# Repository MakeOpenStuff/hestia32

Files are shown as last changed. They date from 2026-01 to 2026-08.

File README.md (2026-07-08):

# Hestia32




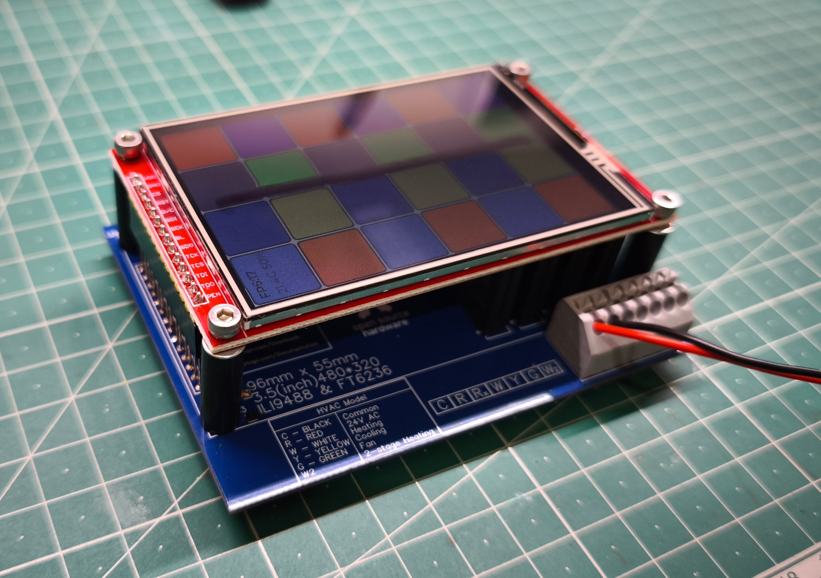
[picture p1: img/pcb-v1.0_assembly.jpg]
Hestia32 PCB Assembly


ESP32 firmware with WiFi provisioning, OTA updates, ILI9488 display, resistive touch and factory reset support.

## Supported Hardware

- **ESP32-C5** - RISC-V based ESP32 variant
- **ILI9488 Display** - 3.5" 320x480 IPS display with XPT2046 resistive touch

## Features

### HVAC Control
- **Multi-stage thermostat logic** - Separate control for heating, cooling, and hot water domains
- **Stage 2 support** - Progressive power control with time-delay and deviation thresholds
- **Comfort and ECO modes** - Adjustable temperature deadbands (±0.5°C comfort, ±1.0°C eco)
- **Hysteresis protection** - 5-minute delay prevents rapid mode switching
- **Fan pre/post-run** - Ensures airflow before heating elements activate and distributes residual heat/cool
- **Open-window detection** - Automatically suspends heating on rapid temperature drops to save energy

### Per-Domain Boost Feature
- Temporarily override thermostat logic for heating, cooling, or hot water
- Maximum output for user-defined countdown period
- Independent boost timer and duration memory per domain
- Automatic return to normal operation when boost expires

### Hardware & UI
- **3.5" ILI9488 Display** (320x480 IPS) with resistive touch (XPT2046)
- **LVGL-based graphical interface** with smooth animations
- **Automatic touch calibration** on first boot
- **Resistive touch coordinate mapping** for accurate input
- **Configurable sensor input** (SHT45 temperature/humidity)
- **5× SPST-NO dry-contact relay outputs** — shared common terminal plus five independent returns; activating a relay shorts its return to common (wire common to R in HVAC systems or N in EU mains wiring)

### Communication & Provisioning
- **WiFi provisioning** via web interface in AP (access point) mode
- **OTA (Over-The-Air) firmware updates** with stable/develop channel selection
- **Multiple protocol support:**
  - **MQTT** (fully implemented, production-ready)
  - **Zigbee** (protocol stub, framework ready)
  - **Matter** (protocol stub, framework ready)
- **Configurable node name and OTA server URL**
- **Factory reset** via BOOT button long-press (5 seconds)
- **NVS persistent storage** for WiFi credentials, calibration, and user settings

### Hardware Variants
- **ESP32-C5 RISC-V** - Primary target (full support)
- **Multiple board profiles:**
  - DevKit (standard GPIO pin assignment)
  - XIAO (compact form factor, alternative pins)
- **Regional variants:**
  - EU (European power levels and configurations)
  - HVAC (heating/cooling optimized)

## Prerequisites

### Display Hardware (ESP32-C5)
- **ILI9488 3.5" IPS Display** (320x480 resolution)
- **XPT2046 Touch Controller** (resistive)
- See [WIRING.md](WIRING.md) for complete pin connections
- **Important:** Display MISO must be disconnected - GPIO 2 is dedicated to touch controller

### For ESP32 (PlatformIO)
- [PlatformIO](https://platformio.org/) installed
- USB drivers for your ESP32 board

### For ESP32-C5 (ESP-IDF v5.5)
- ESP-IDF v5.5.2 or later (official C5 support)
- Python 3.8+
- CMake 3.16+
- Ninja build system

### For Testing (Native Host)
- GCC or Clang compiler with C11 support
- Make (optional, for convenient build commands)

## Building and Flashing

### Clone Repository

**Important:** This project uses git submodules (LVGL). Always clone with `--recursive`:

```bash
# Clone with submodules
git clone --recursive https://github.com/MakeOpenStuff/hestia32.git
cd hestia32

# Or if you already cloned without --recursive:
git submodule update --init --recursive
```

### ESP32 (NodeMCU-32S) - PlatformIO

```bash
# Build
pio run -e nodemcu-32s

# Upload
pio run -e nodemcu-32s -t upload

# Monitor
pio device monitor
```

### ESP32-C5 - Native ESP-IDF

#### First Time Setup

```bash
# Clone ESP-IDF v5.5.2 (one time only)
cd ~/esp
git clone --recursive --branch v5.5.2 https://github.com/espressif/esp-idf.git esp-idf-v5.5

# Install ESP-IDF tools for ESP32-C5 (one time only)
cd ~/esp/esp-idf-v5.5
./install.sh esp32c5
```

#### Protocol Selection

Hestia32 supports multiple communication protocols. Choose one when building:

**MQTT over WiFi (Default - Fully Implemented)**
```bash
idf.py -D SDKCONFIG_DEFAULTS=sdkconfig.mqtt build
```

**Zigbee (Stub Only - Not Yet Implemented)**
```bash
idf.py -D SDKCONFIG_DEFAULTS=sdkconfig.zigbee build
```

**Matter (Stub Only - Not Yet Implemented)**
```bash
idf.py -D SDKCONFIG_DEFAULTS=sdkconfig.matter build
```

You can also select the protocol interactively:
```bash
idf.py menuconfig
# Navigate to: Hestia32 Configuration → Communication Protocol
```

To check which protocol is currently selected:
```bash
grep "CONFIG_HESTIA32_PROTOCOL" sdkconfig
```

#### Build Commands

```bash
# Set up environment (required in each new terminal session)
source ~/esp/esp-idf-v5.5/export.sh

# Or use the provided script
./setup-c5.sh

# Configure target (first time only)
idf.py set-target esp32c5

# Build firmware
idf.py build

# Erase flash (removes all data including WiFi credentials)
idf.py -p /dev/ttyUSB0 erase-flash

# Flash firmware
idf.py -p /dev/ttyUSB0 flash

# Monitor serial output
idf.py -p /dev/ttyUSB0 monitor

# Flash and monitor in one command
idf.py -p /dev/ttyUSB0 flash monitor
```

**Note:** Replace `/dev/ttyUSB0` with your actual serial port (e.g., `/dev/ttyACM0`, `COM3` on Windows, `/dev/cu.usbserial-*` on macOS). Also prefer the (upper) port labelled UART (avoid USB or Native).

## Testing

### Thermostat Logic Tests

The firmware includes a comprehensive test suite for the thermostat control logic that runs on your development machine (not on the ESP32).

#### Running Tests

```bash
# Quick test (using Makefile)
make test

# Or manually build and run
gcc -Wall -Wextra -std=c11 -I. src/thermostat.c tests/test_thermostat.c -o test_thermostat -lm && ./test_thermostat
```

#### Test Coverage

The test suite validates:

1. **Configuration validation** - Domain limits, setpoint sanity checks
2. **Hysteresis protection** - Prevents rapid state changes (300s delay)
3. **Comfort deadband** - Temperature activation thresholds (±0.5°C)
4. **ECO deadband** - Wider temperature band for energy savings (±1.0°C)
5. **Stage 2 heating** - Gradual power increase with delay + deviation logic
6. **Stage 2 cooling** - Gradual power increase with delay + deviation logic
7. **Mutual exclusion** - Heating and cooling never run simultaneously
8. **Sensor failure safety** - Automatic shutdown on sensor faults
9. **Temperature units** - Celsius and Fahrenheit conversion
10. **Fan control** - Pre-run (30s), post-run (60s), and manual override
11. **Humidity control** - Humidification and dehumidification with deadband
12. **Hot water demand** - On-demand hot water heating
13. **Fan timing** - Comprehensive pre-run and post-run validation
14. **Hysteresis + HVAC** - State change delays with fan coordination
15. **Comfort deadband + HVAC** - Temperature thresholds with fan safety
16. **ECO deadband + HVAC** - Energy-saving mode with fan coordination
17. **Stage 2 heating + HVAC** - Multi-stage heating with fan timing
18. **Stage 2 cooling + HVAC** - Multi-stage cooling with fan timing
19. **Mutual exclusion + HVAC** - No simultaneous operation through all fan phases
20. **Sensor failure + HVAC** - Immediate shutdown including fan (safety critical)
21. **Open window detection** - Detects rapid temperature drops, suspends heating to save energy
22. **Open window false positive prevention** - Validates gradual changes don't trigger detection

**Scenario Testing:**
- **24-hour simulation** - Complete heating cycle with realistic temperature changes

**Key Features Validated:**
- Fan pre-run ensures airflow before thermal elements activate (prevents dry running)
- Fan post-run distributes residual heat/cool after thermal stops
- Minimum cycle time (180s) protects equipment from short cycling
- Hysteresis period (300s) prevents rapid mode switching
- Stage 2 activation requires both time delay (300s) AND temperature deviation (0.75°C)
- All outputs shut down immediately on sensor failure (safety)
- Manual fan override works independently of thermal state

#### Test Output

Tests produce color-coded output (green = pass, red = fail) with:
- Related configuration for each test
- Step-by-step execution traces
- Final summary table with pass/fail counts

```
=== TEST 1: Configuration Validation ===
Testing: thermostat_config_validate() with various invalid configs
...
✓ PASSED: Configuration Validation

=== SUMMARY ===
Total Tests: 12
Passed: 12
Failed: 0
Success Rate: 100.00%
```

#### Continuous Testing

Run tests before committing changes to ensure thermostat logic correctness:

## Usage

### Initial Setup (Provisioning)

1. Flash the firmware to your device
2. On first boot, the device creates a WiFi access point:
	 - **SSID:** `HESTIA32`
	 - **Password:** None (open network)
3. Connect to the `HESTIA32` WiFi network
4. Open a web browser and navigate to `http://192.168.4.1`
5. Enter your WiFi credentials and configuration:
	 - WiFi SSID
	 - WiFi Password
	 - Node Name (optional)
	 - OTA Server URL (optional)
6. Click Save - the device will restart and connect to your WiFi

### Factory Reset

To erase WiFi credentials, touch calibration, and return to provisioning mode:

1. Power off the device
2. Press and hold the **BOOT** button
3. Power on the device (or press RESET while holding BOOT)
4. Keep holding the BOOT button for **5 seconds**
5. Release when you see "Factory reset confirmed!" in the serial monitor
6. The device will erase all NVS data and reboot into provisioning mode

**BOOT Button GPIO:**
- ESP32 (original): GPIO 0
- ESP32-C5: GPIO 28

**Troubleshooting:** Check serial monitor for "BOOT button GPIO X level: 0" when button is pressed. If it shows "1", the GPIO may be incorrect for your board.

## Configuration

Edit `src/config.h` to customize:

```c
#define PROV_AP_SSID "HESTIA32"          // Provisioning AP name
#define PROV_AP_PASSWORD ""               // AP password (empty = open)
#define OTA_SERVER_URL "https://..."      // Default OTA server
#define OTA_CHECK_INTERVAL_MS 300000      // OTA check interval (5 min)
#define APP_VERSION "1.0.0"               // Firmware version
```

## Project Structure

```
hestia32/
├── src/
│   ├── main.c                      # Application entry point
│   ├── core/                       # Core thermostat & hardware functionality
│   │   ├── core_config.h           # Firmware version and core settings
│   │   ├── thermostat.c/h          # HVAC control logic (stages, hysteresis, deadbands)
│   │   ├── relay_manager.c/h       # Heating, cooling, hot water, fan output control
│   │   ├── sensor_sht45.c/h        # Temperature/humidity sensor interface
│   │   ├── protocol_manager.c/h    # Protocol abstraction and selection
│   │   ├── user_settings.c/h       # NVS persistent storage (WiFi, calibration, settings)
│   │   ├── display_manager.h       # Display abstraction layer
│   │   ├── display_ui.h            # LVGL UI components and screens
│   │   └── display_config.h        # Display initialization (ILI9488, XPT2046)
│   └── protocols/                  # Communication protocol implementations
│       ├── protocol_interface.h    # Common interface for all protocols
│       ├── mqtt/                   # MQTT over WiFi (production-ready)
│       │   ├── mqtt_protocol.c/h   # MQTT client and message handling
│       │   ├── wifi_manager.c/h    # WiFi connection management
│       │   ├── wifi_provisioning.c/h # Web-based provisioning (AP mode)
│       │   ├── ota_manager.c/h     # OTA update checking and flashing
│       │   ├── mqtt_config.h       # MQTT broker configuration
│       │   └── provisioning_html.h # Embedded provisioning web UI
│       ├── zigbee/                 # Zigbee (protocol stub)
│       │   └── protocol_zigbee.c/h
│       └── matter/                 # Matter (protocol stub)
│           └── protocol_matter.c/h
├── components/
│   ├── esp_lcd_ili9488/            # ILI9488 display driver
│   └── lvgl/                       # LVGL graphics library (submodule)
├── pcb/                            # Hardware designs and manufacturing files
│   └── README.md                   # PCB revision history and board notes
├── docs/                           # Technical documentation
│   ├── display/                    # Display configuration guides
│   ├── esp32-c5/                   # ESP32-C5 specific documentation
│   └── sensors/                    # Sensor integration docs
├── tests/
│   ├── test_thermostat.c           # Comprehensive thermostat logic test suite (24 tests)
│   └── Makefile                    # Test build automation
├── platformio.ini                  # PlatformIO configuration (ESP32 support)
├── CMakeLists.txt                  # ESP-IDF build config (ESP32-C5 primary)
├── sdkconfig.defaults              # ESP-IDF default settings
├── sdkconfig.mqtt/zigbee/matter    # Protocol-specific SDK configurations
├── Makefile                        # Build and test automation
├── setup-c5.sh                     # ESP32-C5 environment setup script
├── WIRING.md                       # Complete pin mapping for all board variants
├── Hestia32-FSD.md                 # Functional specification document
└── README.md                       # This file
```

## Troubleshooting

### ESP32-C5 Build Issues

**Error: `idf.py: command not found`**
```bash
source ~/esp/esp-idf-v5.5/export.sh
```

**Error: WiFi/PHY undefined references**
- Make sure you're using ESP-IDF v5.5.1 or later
- ESP32-C5 support is incomplete in earlier versions

**Error: unexpected command options**
- Use plain `idf.py` commands with no extra preview options

### Serial Port Not Found

```bash
# Linux - check available ports
ls /dev/tty*

# Add user to dialout group (Linux)
sudo usermod -a -G dialout $USER
# Log out and back in for changes to take effect

# macOS - check available ports
ls /dev/cu.*
```

### Device Stuck in Provisioning Mode

If the device won't connect to WiFi after provisioning:

1. Check serial monitor for error messages
2. Verify WiFi credentials are correct
3. Perform factory reset and re-provision
4. Check that your WiFi network is 2.4GHz (ESP32 doesn't support 5GHz)

### Test Failures

If thermostat tests fail:

1. Check that you have a C11-compatible compiler:
	 ```bash
	 gcc --version  # Should be 4.9 or later
	 ```

2. Ensure all source files are present:
	 ```bash
	 ls src/thermostat.c src/thermostat.h tests/test_thermostat.c
	 ```

3. Run with verbose output to see which test failed:
	 ```bash
	 ./build/test_thermostat
	 ```

4. If colors don't display correctly, your terminal may not support ANSI codes

## TODO

### Known Issues & Pending Tasks

- [ ] **WiFi Model**
	- [ ] Fix serial logging on DevKit - Serial output stops after bootloader on ESP32-C5 DevKit, investigate USB re-enumeration or UART configuration
	- [ ] Verify SHT45 operation on DevKit - Confirm sensor reads correctly with swapped I2C pins (SDA=GPIO5, SCL=GPIO4)
	- [ ] Update WIRING.md pinout diagram - Reconcile conflicting GPIO assignments in DevKit pinout diagram vs. connection tables
	- [ ] Update Project Structure section - Reflect current codebase organization with display, relay, and sensor modules
- [ ] **UI Design & Implementation**
	- [ ] Design and implement main thermostat control interface
	- [ ] Create settings/configuration screens
	- [ ] Implement touch interactions and navigation
	- [ ] Add visual feedback for heating/cooling states
- [ ] **Zigbee Model**
- [ ] **Matter Model**

## License

This project uses a dual-license model:

- **Code and firmware** (e.g. `src/`, `components/`, build scripts) are licensed under **GNU General Public License v3.0 (GPL-3.0)**. See `LICENSE`.
- **Documentation and hardware artifacts** (e.g. `*.md`, `pcb/`, schematics, manufacturing outputs, media) are licensed under **Creative Commons Attribution-ShareAlike 4.0 International (CC BY-SA 4.0)**. See `LICENSE-CC-BY-SA-4.0.md`.

Third-party dependencies keep their own licenses.

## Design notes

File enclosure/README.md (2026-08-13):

# Enclosure

This folder contains the printable enclosure parts for the Hestia32 device.

## Contents
- Base enclosure: mounts to the wall and houses the main PCB
- Cover enclosure: snaps onto the base and holds the display

## TODO
- [ ] Add guides on the base to help screen and cover alignment on closure
- [ ] Center screen vertically
- [ ] Document the required threaded inserts
- [ ] Improve cable management
- [ ] Add labeled assembly instructions and exploded-view notes

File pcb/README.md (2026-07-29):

# PCB Variants

This folder contains PCB Gerber files ready for manufacturing, Bill of Materials (BOM) and notes for Hestia32 hardware variants.

## Variant Matrix

There are 4 possible PCB variants from two feature axes:

- Board target: `DevKit` or `XIAO`
- Product profile: `EU` or `HVAC`

Resulting variants:

| Variant | Folder | BOM | Interactive BOM |
|---|---|-----|---|
| DevKit-EU | DevKit-EU/ | - | - |
| DevKit-HVAC | DevKit-HVAC/ | - | - |
| XIAO-EU | [XIAO-EU/](XIAO-EU/) | [BOM](https://github.com/MakeOpenStuff/hestia32/blob/develop/pcb/XIAO-EU/BOM_Hestia32-EU_XIAO.csv) | [iBOM](https://htmlpreview.github.io/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) |
| XIAO-HVAC | [XIAO-HVAC/](XIAO-HVAC/) | [BOM](https://github.com/MakeOpenStuff/hestia32/blob/develop/pcb/XIAO-HVAC/BOM_Hestia32-HVAC_XIAO.csv) | [iBOM](https://htmlpreview.github.io/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) |

## History

### XIAO-HVAC
- `v1.6`:
  - Optimise thermal properties (remove copper fill around sensor and add air gap)
- `v1.5`:
  - No funtional change
  - Added LCD SDO (MISO) test point
  - Changed label 3V3 to XIAO_3V3 to avoid users driving heavy loads
- `v1.4`:
  - Split versioning between HVAC and EU PCB designs
  - Use LM2596HVS instead of LM2596S

### XIAO-EU
- `v1.6`:
  - Optimise thermal properties (remove copper fill around sensor and add air gap)
- `v1.5`:
  - Fixed GND test point
  - Increase track width for AC NETs
- `v1.4`:
  - No funtional change
  - Added LCD SDO (MISO) test point
  - Changed label 3V3 to XIAO_3V3 to avoid users driving heavy loads

### Shared for both XIAO-HVAC and XIAO-EU
- `v1.3`:
  - XIAO-HVAC: Used coil relays instead of solid-state relays
  - XIAO-HVAC: Used LM2596 for power supply
  - XIAO-HVAC: Improved filtering
  - XIAO-HVAC: Supported heat pumps
  - XIAO-EU: Used coil relays instead of solid-state relays
  - XIAO-EU: Improved filtering
  - XIAO-EU: Supported heat pumps
- `v1.2`:
  - Improve sensor location
	- Improve via stitching
	- Add extra info on silkscreen
- `v1.1`:
  - Fix I2C pull up resistors
  - Renumerate components prefixes without gaps
  - Add unpopulated additional GPIOs pins from port expander (P07)
  - Increase clearance around holes in case user uses large metal screw or washer
  - Add extra information on top silkscreen
- `v1.0`:
  - First complete PCB design release for the Hestia32 XIAO variant.

## TODO (Future Improvements)

- [x] Develop XIAO-EU
  - [x] Schematic
  - [x] BOM
  - [x] Gerber
  - [x] Use coil relays instead of solid-state relays
  - [x] Support heat pumps
  - [x] Improve filtering
- [x] Develop XIAO-HVAC
  - [x] Schematic
  - [x] BOM
  - [x] Gerber
  - [x] Use coil relays instead of solid-state relays
  - [x] Support heat pumps
  - [x] Use LM2596 for power supply
  - [x] Improve filtering
- [x] Renumber components prefixes without gaps
- [x] Add unpopulated additional GPIOs pins from port expander
- [x] Increase clearance around holes in case user uses large metal screw or washer
- [ ] Develop DevKit-EU
  - [ ] Schematic
  - [ ] BOM
  - [ ] Gerber
  - [ ] Use coil relays instead of solid-state relays
  - [ ] Support heat pumps
  - [ ] Improve filtering
- [ ] Develop DevKit-HVAC
  - [ ] Schematic
  - [ ] BOM
  - [ ] Gerber
  - [ ] Use coil relays instead of solid-state relays
  - [ ] Support heat pumps
  - [ ] Use LM2596 for power supply
  - [ ] Improve filtering

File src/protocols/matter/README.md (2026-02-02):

# Matter Protocol Implementation

**Status:** Not yet implemented (stub only)

## Overview

This directory contains stub implementation for Matter protocol support. Matter enables the Hestia32 thermostat to work with Apple HomeKit, Google Home, Amazon Alexa, and other Matter-certified ecosystems.

## Implementation Plan

### Phase 1: Matter Device Commissioning
- [ ] Initialize ESP Matter SDK
- [ ] Implement Matter thermostat device type
- [ ] QR code/manual pairing code generation
- [ ] Wi-Fi/Thread commissioning
- [ ] Basic attribute reporting

### Phase 2: Thermostat Cluster Implementation
- [ ] Local temperature reporting
- [ ] Occupied heating/cooling setpoint
- [ ] System mode (Off/Heat/Cool/Auto)
- [ ] Running state (Idle/Heating/Cooling)
- [ ] Control sequence of operation

### Phase 3: Advanced Features
- [ ] Relative humidity measurement cluster
- [ ] Fan control cluster
- [ ] Custom boost mode cluster
- [ ] OTA firmware updates via Matter
- [ ] Multi-fabric support (Apple + Google simultaneously)

### Phase 4: Optimization
- [ ] Low-power modes
- [ ] Subscription management
- [ ] Persistent ACL storage
- [ ] Network failover (Wi-Fi ↔ Thread)

## Required Components

- **ESP Matter SDK**: ESP-IDF v5.1+ with Matter libraries
- **Hardware**: ESP32-C5 supports Matter over Wi-Fi and Thread
- **Memory**: ~400KB flash, ~100KB RAM overhead
- **Certification**: Optional Matter certification for production

## Matter Clusters to Implement

| Cluster | ID | Purpose |
|---|-----|---|
| Thermostat | 0x0201 | HVAC control, setpoints, modes |
| Temperature Measurement | 0x0402 | Current temperature reporting |
| Relative Humidity | 0x0405 | Humidity reporting |
| Fan Control | 0x0202 | Fan speed/mode |
| On/Off | 0x0006 | Relay control |
| Identify | 0x0003 | Device identification |

## Device Type

**Thermostat (Device Type ID: 0x0301)**
- Server clusters: Thermostat, Temperature Measurement, Humidity, Fan Control
- Client clusters: None
- Endpoint: 1

## Configuration

Matter-specific settings will be stored in `matter_config.h`:
- Vendor ID (VID)
- Product ID (PID)
- Device name
- Commissioning timeout
- Attribute reporting intervals

## Commissioning Flow

1. User initiates commissioning via Matter controller app
2. Device generates pairing QR code (shown on display)
3. Controller scans QR code
4. BLE/Wi-Fi commissioning completes
5. Device joins Matter fabric
6. Operational credentials exchanged
7. Device ready for control

## Testing

1. Commission with Apple Home
2. Commission with Google Home (multi-fabric)
3. Verify attribute reporting
4. Test remote setpoint changes
5. Validate mode switching
6. Test OTA updates
7. Power cycle recovery

## Resources

- [ESP Matter SDK Documentation](https://docs.espressif.com/projects/esp-matter/)
- [Matter Specification](https://csa-iot.org/developer-resource/specifications-download-request/)
- [Matter Device Types](https://github.com/project-chip/connectedhomeip/tree/master/src/app/clusters)
- [Apple HomeKit Matter Support](https://developer.apple.com/smart-home/)
- [Google Home Matter Integration](https://developers.home.google.com/matter)

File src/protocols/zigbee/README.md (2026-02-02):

# Zigbee Protocol Implementation

**Status:** Not yet implemented (stub only)

## Overview

This directory contains stub implementation for Zigbee protocol support. The Zigbee protocol allows the Hestia32 thermostat to communicate with Zigbee smart home ecosystems like Home Assistant, Zigbee2MQTT, or proprietary Zigbee hubs.

## Implementation Plan

### Phase 1: Basic Zigbee End Device
- [ ] Initialize ESP Zigbee SDK
- [ ] Implement Zigbee thermostat cluster (HVAC)
- [ ] Device commissioning/pairing
- [ ] Basic attribute reporting (temperature, setpoint, mode)

### Phase 2: Advanced Features
- [ ] Relative humidity measurement cluster
- [ ] Fan control cluster
- [ ] Boost mode custom cluster
- [ ] OTA firmware updates via Zigbee
- [ ] Multi-relay control

### Phase 3: Optimization
- [ ] Power management (sleep modes)
- [ ] Network rejoin handling
- [ ] Persistent binding configuration

## Required Components

- **ESP Zigbee SDK**: ESP-IDF v5.1+ with Zigbee libraries
- **Hardware**: ESP32-C5 supports Zigbee 3.0 and Thread
- **Memory**: ~200KB flash, ~50KB RAM overhead

## Zigbee Clusters to Implement

| Cluster | ID | Purpose |
|---|-----|---|
| Thermostat | 0x0201 | HVAC control, setpoints, modes |
| Temperature Measurement | 0x0402 | Current temperature reporting |
| Relative Humidity | 0x0405 | Humidity reporting |
| Fan Control | 0x0202 | Fan speed/mode |
| On/Off | 0x0006 | Relay control |

## Configuration

Zigbee-specific settings will be stored in `zigbee_config.h`:
- Network channel
- PAN ID
- Join timeout
- Reporting intervals

## Testing

1. Pair with Zigbee coordinator (e.g., Zigbee2MQTT)
2. Verify attribute reporting
3. Test remote setpoint changes
4. Validate mode switching
5. Test power cycle recovery

## Resources

- [ESP Zigbee SDK Documentation](https://docs.espressif.com/projects/esp-zigbee-sdk/)
- [Zigbee Cluster Library Specification](https://zigbeealliance.org/developer_resources/zigbee-cluster-library/)
- [Home Assistant Zigbee Integration](https://www.home-assistant.io/integrations/zha/)

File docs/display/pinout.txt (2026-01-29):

# Product parameters:

Size :3.5 inch
Type :TFT
Drive IC:
TN-ILI9488 (Wide View)
IPS-ILI9488(IPS Full View)
Resolution:480*320 pixel
Module interface:4-wire SPI interface
Effective display area (AA area):48.96*73.44 mm
Dimensions of module PCB bottom plate:55.1*96.18 mm
VCC supply voltage:3.3 V~5 V
Logic IO port voltage:3.3V(TTL)
Power consumption:about 90mA
Product weight:25(g)

# Interface definition

1/VCC/Power input (3.3 V~5V)
2/GND/Power supply ground
3/CS/LCD/chip select (CS)
4/RESET/LCD reset
5/DC/LCD Bus command/data selection
6/SDI(MOSI)LCD SPI Display bus data input
7/SCK/LCD SPI Display bus clock signal
8/LED/LCD Backlight control (high level lighting)
9/SDO(MISO)LCD SPI Displays the total data input/output
10/T_CLK/Touch panel SPI bus clock signal
11/T_CS/Chip selection of SPI bus for touch panel
12/T_DIN/Touch panel SPI bus data input
13/T_DO/Touch panel SPI bus data output
14/T_IRQ/Touch panel interrupts IRQ signal

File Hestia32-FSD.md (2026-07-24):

# Hestia32 Firmware - Functional Specification Document (FSD)

**Document Version:** 1.2
**Firmware Version:** 0.9.0
**Date:** April 25, 2026

---

## Table of Contents

1. [Executive Summary](#1-executive-summary)
2. [Project Overview](#2-project-overview)
3. [System Architecture](#3-system-architecture)
4. [Hardware Requirements](#4-hardware-requirements)
5. [Functional Requirements](#5-functional-requirements)
6. [Module Specifications](#6-module-specifications)
7. [User Interface](#7-user-interface)
8. [Data Management](#8-data-management)
9. [Security Considerations](#9-security-considerations)
10. [Development Environment](#10-development-environment)
11. [Build and Deployment](#11-build-and-deployment)
12. [Testing Strategy](#12-testing-strategy)
13. [Future Roadmap](#13-future-roadmap)
14. [Appendices](#14-appendices)

---

## 1. Executive Summary

Hestia32 is an ESP32-based firmware platform designed for IoT applications with a focus on HVAC/thermostat control and user interaction through a graphical touchscreen display. The system features WiFi provisioning without hardcoded credentials, Over-The-Air (OTA) firmware updates and a modern LVGL-based user interface on a 3.5" ILI9488 display with resistive touch support.

**Key Features:**
- Web-based WiFi provisioning (captive portal)
- Secure OTA firmware updates with dual partition support
- LVGL-driven graphical UI with touch calibration
- Advanced multi-stage thermostat control logic
- Factory reset capability via BOOT button
- NVS-based persistent storage for credentials and calibration
- Support for ESP32 (original) and ESP32-C5 (RISC-V)

---

## 2. Project Overview

### 2.1 Purpose

Hestia32 provides a complete firmware solution for ESP32-based smart home devices, specifically targeting thermostat and HVAC control applications. The firmware abstracts common IoT requirements (WiFi management, OTA updates, display handling) into reusable modules while providing a robust thermostat control engine.

### 2.2 Target Applications

- Smart thermostats
- HVAC control systems
- Multi-stage heating/cooling systems
- Humidity control systems
- General-purpose ESP32 IoT devices with display

### 2.3 Supported Hardware Platforms

| Platform | Architecture | Status | Build System |
|---|---|---|---|
| ESP32 (NodeMCU-32S) | Xtensa LX6 | Supported | PlatformIO |
| ESP32-C5 | RISC-V | Supported | ESP-IDF v5.5 |

### 2.4 Design Philosophy

- **Modularity:** Independent functional modules (WiFi, OTA, Display, Thermostat)
- **Zero Configuration:** No hardcoded WiFi credentials; provision via web interface
- **Safety First:** Sensor failure detection, mutual exclusion in thermostat logic
- **User Experience:** Touch calibration wizard, responsive UI, clear feedback
- **Maintainability:** Clean code structure, comprehensive test coverage

---

## 3. System Architecture

### 3.1 High-Level Architecture

```
┌────────────────────────────────────────────────────────────┐
│                    Application Layer                       │
│   main.c | UI update loop | sensor polling | runtime reset │
└────────────────────────────────────────────────────────────┘
                             │
┌────────────────────────────────────────────────────────────┐
│                      Core Layer                            │
│ display_manager | display_ui | thermostat | relay_manager  │
│ sensor_sht45 | user_settings | protocol_manager            │
└────────────────────────────────────────────────────────────┘
                             │
┌────────────────────────────────────────────────────────────┐
│                    Protocol Layer                          │
│ MQTT (implemented) | Zigbee (stub) | Matter (stub)         │
│ WiFi provisioning and OTA are under protocols/mqtt         │
└────────────────────────────────────────────────────────────┘
                             │
┌────────────────────────────────────────────────────────────┐
│                  ESP-IDF + Hardware                        │
│ WiFi | NVS | SPI | I2C | GPIO | FreeRTOS | LCD/Touch       │
└────────────────────────────────────────────────────────────┘
```

### 3.2 Boot Sequence

```
1. Power On / Reset
   └─> NVS Initialization
       └─> Continue boot (factory reset is handled at runtime via BOOT long-press)

2. Touch Calibration Check
   └─> Has calibration data in NVS?
       ├─> No: Run calibration wizard → Save to NVS → Restart
       └─> Yes: Load calibration

3. WiFi Provisioning Check
   └─> Is device provisioned?
       ├─> No: Start AP mode → Launch web server → Wait for config
       └─> Yes: Continue

4. Display Initialization
   └─> Initialize SPI + ILI9488 + XPT2046
       └─> Start LVGL task
           └─> Create main UI

5. WiFi Connection
   └─> Load credentials from NVS
       └─> Connect to WiFi (5 retries)

6. OTA Initialization
   └─> Verify boot partition
       └─> Mark as valid if pending

7. Main Loop
   └─> Application logic (sensor polling + runtime BOOT long-press reset)
```

### 3.3 Task Priority Structure

| Task | Priority | Purpose | Core Affinity |
|---|---|---|---|
| WiFi/Network Tasks | 20-23 | ESP-IDF WiFi stack (system) | Any |
| DNS Server | 5 | Captive portal DNS resolution | Any |
| LVGL Task | 3 | UI rendering and touch handling | Any |
| Display Provisioning | 2 | Low-priority UI during setup | Any |
| Main Task | 1 | Initialization, then suspended | Any |

---

## 4. Hardware Requirements

### 4.1 ESP32-C5 Configuration

**Microcontroller:**
- ESP32-C5 (RISC-V 32-bit, single core)
- Flash: 4MB minimum (dual OTA partitions)
- RAM: 512KB SRAM

**Display Module:**
- Controller: ILI9488
- Size: 3.5 inches
- Resolution: 320×480 pixels (portrait)
- Interface: SPI (write-only, 40MHz)
- Panel Type: IPS
- Backlight: PWM-controlled via GPIO 13

**Touch Controller:**
- Type: XPT2046 (resistive)
- Interface: SPI (shared bus, 1MHz)
- Pressure sensing: Active low IRQ (GPIO 15)

### 4.2 Pin Mapping (ESP32-C5)

Pin mapping is board-profile dependent and selected through Kconfig (`CONFIG_BOARD_TYPE_DEVKIT` or `CONFIG_BOARD_TYPE_XIAO`).

**ESP32-C5 DevKit Profile**

| Function | GPIO | Notes |
|---|---|---|
| **Display SPI** |||
| MOSI (SDI) | 7 | Shared with touch |
| SCLK | 6 | Shared with touch |
| CS | 10 | Display chip select |
| DC (RS) | 8 | Data/Command select |
| RESET | 9 | Hardware reset |
| Backlight | 13 | PWM capable |
| **Touch SPI** |||
| T_CS | 14 | Touch chip select |
| T_DIN | 7 | Shared MOSI |
| T_CLK | 6 | Shared SCLK |
| T_DO (MISO) | 2 | Dedicated (display MISO disconnected) |
| T_PEN (IRQ) | 15 | Active low pen detect |
| **I2C** |||
| SCL | 4 | SHT45 on DevKit profile |
| SDA | 5 | SHT45 on DevKit profile |

**XIAO ESP32-C5 Profile**

| Function | GPIO | Notes |
|---|---|---|
| **Display SPI** |||
| MOSI (SDI) | 10 | Shared with touch |
| SCLK | 8 | Shared with touch |
| CS | 7 | Display chip select |
| DC (RS) | 1 | Data/Command select |
| RESET | 25 | Hardware reset |
| Backlight | 0 | PWM capable |
| **Touch SPI** |||
| T_CS | 12 | Touch chip select |
| T_DIN | 10 | Shared MOSI |
| T_CLK | 8 | Shared SCLK |
| T_DO (MISO) | 9 | Touch MISO |
| T_PEN (IRQ) | 11 | Active low pen detect |
| **I2C** |||
| SCL | 24 | TCA9555 + SHT45 |
| SDA | 23 | TCA9555 + SHT45 |

**System (Both Profiles)**

| Function | GPIO | Notes |
|---|---|---|
| BOOT Button | 28 | Runtime factory reset (hold 5s while running) |

**Critical Notes:**
- Display SDO/MISO **must remain disconnected**; GPIO 2 is dedicated to touch controller
- SPI2_HOST used for both display and touch (different CS pins)
- XIAO and DevKit use different GPIO maps; do not cross-wire between profiles

### 4.3 Power Requirements

- Supply voltage: 3.3V regulated
- Typical current: 150-200mA (backlight on)
- Backlight off: 20-30mA
- Recommended: 100µF capacitor near display VCC/GND

### 4.4 Environmental Sensors

**SHT45 Temperature & Humidity Sensor:**
- Interface: I2C (address 0x44)
- SCL/SDA: GPIO 4/5 (DevKit), GPIO 24/23 (XIAO)
- Accuracy: ±0.1°C, ±1% RH
- Range: -40°C to 125°C, 0-100% RH
- Power: 0.4µA (sleep), 800µA (measurement)

### 4.5 ESP32 (Original) Configuration

For NodeMCU-32S boards using PlatformIO, pin assignments differ. Refer to `display_config.h` for specific GPIO mappings. The BOOT button is typically GPIO 0.

---

## 5. Functional Requirements

### 5.1 FR-001: WiFi Provisioning

**Priority:** Critical
**Status:** Implemented

**Description:** Device shall support web-based WiFi configuration without requiring hardcoded credentials.

**Acceptance Criteria:**
1. On first boot (no saved credentials), device creates open AP with SSID "HESTIA32"
2. Captive portal redirects all HTTP requests to 192.168.4.1
3. Web interface displays WiFi network scan results
4. User can input: WiFi SSID, password, device name, OTA server URL
5. Configuration saved to NVS persistent storage
6. Device restarts and connects to configured WiFi automatically

**Dependencies:** NVS, ESP WiFi stack, HTTP server

---

### 5.2 FR-002: Factory Reset

**Priority:** High
**Status:** Implemented

**Description:** User shall be able to erase all stored settings and return device to provisioning mode.

**Acceptance Criteria:**
1. Hold BOOT button while firmware is running
2. Continue holding for 5 seconds
3. System erases NVS (WiFi credentials + touch calibration)
4. Device restarts in provisioning mode
5. Serial console logs "Factory reset confirmed!"

**Dependencies:** GPIO, NVS

---

### 5.3 FR-003: OTA Firmware Updates

**Priority:** Critical
**Status:** Implemented (update mechanism; version check optional)

**Description:** Device shall support secure over-the-air firmware updates with rollback protection.

**Acceptance Criteria:**
1. Dual OTA partition support (ota_0, ota_1)
2. HTTPS download from configurable URL
3. Automatic rollback on boot failure (ESP-IDF built-in)
4. Mark successful boot as valid to prevent rollback
5. Optional: Version comparison before download

**Dependencies:** ESP HTTPS OTA library, partition table

---

### 5.4 FR-004: Display and Touch Interface

**Priority:** Critical
**Status:** Implemented

**Description:** Device shall provide graphical user interface with calibrated resistive touch input.

**Acceptance Criteria:**
1. Initialize ILI9488 display (320×480 @ 40MHz SPI)
2. Initialize XPT2046 touch controller (1MHz SPI)
3. Run automatic calibration wizard on first boot
4. User touches 5 crosshairs (corners + center) within 60 seconds
5. Calibration data saved to NVS
6. Touch input mapped correctly to screen coordinates
7. LVGL renders UI at 25+ FPS

**Dependencies:** SPI, LVGL, NVS

---

### 5.5 FR-005: Touch Calibration

**Priority:** High
**Status:** Implemented

**Description:** System shall automatically detect axis orientation and mapping through user calibration.

**Acceptance Criteria:**
1. Calibration wizard displays 5 targets (4 corners + center)
2. 60-second overall timeout; 15 seconds per target
3. System detects axis swap, X flip, Y flip automatically
4. Calibration margins (5%) added to prevent edge clipping
5. If timeout occurs, use default calibration values
6. Calibration data: x_min, x_max, y_min, y_max, swap_xy, flip_x, flip_y

**Dependencies:** Touch hardware, NVS

---

### 5.6 FR-006: Thermostat Control (Planned)

**Priority:** High
**Status:** Not Integrated (module complete, not used in main.c)

**Description:** Device shall provide multi-stage heating/cooling control with advanced features.

**Acceptance Criteria:**
1. Support up to 5 simultaneous domains (heating, cooling, fan, humidity, hot water)
2. Multi-stage heating/cooling with configurable delays
3. Comfort/Eco modes with different deadbands
4. Open window detection (rapid temperature drop suspends heating)
5. Hysteresis protection (minimum 5 minutes between state changes)
6. Minimum cycle time (3 minutes) to protect equipment
7. Fan pre-run (30s before thermal) and post-run (60s after)
8. Mutual exclusion: heating and cooling never active simultaneously
9. Emergency shutdown on sensor failure

**Dependencies:** Temperature/humidity input source and relay/output routing

---

### 5.7 FR-007: Persistent Configuration Storage

**Priority:** Critical
**Status:** Implemented

**Description:** All user settings shall persist across power cycles and firmware updates.

**Acceptance Criteria:**
1. WiFi credentials stored in NVS namespace "wifi_config"
2. Touch calibration stored in NVS namespace "touch_cal"
3. Factory reset erases all NVS data
4. NVS partition: 24KB (0x6000 bytes)

**Dependencies:** NVS Flash API

---

## 6. Module Specifications

### 6.1 WiFi Provisioning Module

**Files:** `src/protocols/mqtt/wifi_provisioning.c/h`, `src/protocols/mqtt/provisioning_html.h`

**Responsibilities:**
- Create WiFi AP (SSID: "HESTIA32", open network)
- Run HTTP server on 192.168.4.1
- Implement captive portal DNS server (port 53)
- Serve HTML configuration form
- Handle WiFi network scanning
- Parse and save user configuration to NVS
- Restart device after successful configuration

**APIs:**
```c
void wifi_prov_init(void);
bool wifi_prov_is_provisioned(void);
void wifi_prov_start_ap(void);
esp_err_t wifi_prov_get_config(wifi_config_data_t *config);
void wifi_prov_reset(void);
```

**Configuration Structure:**
```c
typedef struct {
    char ssid[32];
    char password[64];
    char node_name[32];
    char ota_url[128];
} wifi_config_data_t;
```

**HTTP Endpoints:**
- `GET /` - Configuration form
- `GET /scan` - WiFi network scan (JSON)
- `POST /save` - Save configuration
- `GET /detect` - Captive portal redirect

**DNS Server:**
- Listens on UDP port 53
- Responds to all queries with 192.168.4.1
- Enables captive portal on mobile devices

---

### 6.2 WiFi Manager Module

**Files:** `src/protocols/mqtt/wifi_manager.c/h`

**Responsibilities:**
- Initialize ESP WiFi stack (STA mode)
- Connect to configured WiFi network
- Implement retry logic (default 5 retries)
- Provide connection status

**APIs:**
```c
esp_err_t wifi_init(void);
esp_err_t wifi_connect(const char *ssid, const char *password, int max_retry);
void wifi_disconnect(void);
```

**Event Handling:**
- `WIFI_EVENT_STA_START` → Initiate connection
- `WIFI_EVENT_STA_DISCONNECTED` → Retry logic
- `IP_EVENT_STA_GOT_IP` → Connection successful

---

### 6.3 OTA Manager Module

**Files:** `src/protocols/mqtt/ota_manager.c/h`

**Responsibilities:**
- Verify current boot partition
- Mark valid firmware after successful boot
- Download and install OTA updates via HTTPS
- Automatic rollback on failure

**APIs:**
```c
esp_err_t ota_init(void);
esp_err_t ota_update_from_url(const char *url);
const char* ota_get_version(void);
esp_err_t ota_check_and_update(const char *url);
```

**Partition Table:**
```
nvs       | 0x9000  | 24KB   | Configuration storage
otadata   | 0xF000  | 8KB    | OTA boot state
phy_init  | 0x11000 | 4KB    | PHY calibration
ota_0     | 0x20000 | 1.8MB  | Primary firmware
ota_1     | 0x1F0000| 1.8MB  | Secondary firmware
```

**Update Flow:**
1. Download firmware from URL
2. Write to inactive partition (ota_0 or ota_1)
3. Mark new partition as boot target
4. Restart device
5. On first boot: validate partition → mark as good OR rollback

---

### 6.4 Display Manager Module

**Files:** `src/core/display_manager.cpp/h`, `src/core/display_config.h`

**Responsibilities:**
- Initialize ILI9488 LCD via SPI (write-only, 40MHz)
- Initialize XPT2046 touch controller via SPI (1MHz)
- Configure PWM backlight control
- Initialize LVGL graphics library
- Implement LVGL flush callback (RGB565 → RGB666 conversion)
- Implement touch input callback with calibration mapping
- Run calibration wizard on first boot
- Save/load calibration from NVS

**APIs:**
```c
esp_err_t display_init(void);
bool display_has_calibration(void);
void display_create_ui(bool skip_calibration, bool provisioning_mode);
void display_start_lvgl_task(void);
void display_update(void);  // Legacy, deprecated
void display_clear_screen(void);
```

**LVGL Configuration:**
- Double buffering (board-dependent buffer height)
- RGB565 color mode
- SPI DMA transfer
- Tick period: 2ms
- Target: 25+ FPS

**Touch Calibration Process:**
1. Display 5 crosshair targets sequentially
2. User touches each target
3. Average 8 samples per touch
4. Calculate axis mapping from corner relationships:
   - Compare horizontal/vertical movement to determine if raw X/Y need swapping
   - Detect if X or Y axis needs flipping
5. Save min/max ranges with 5% margin
6. Store to NVS: x_min, x_max, y_min, y_max, swap_xy, flip_x, flip_y

**Touch Input Flow:**
```
XPT2046 raw (0-4095) → Apply calibration clamp → Map to 0-319 / 0-479
→ Apply axis swap (if needed) → Apply flips (if needed) → LVGL coordinates
```

---

### 6.5 Display UI Module

**Files:** `src/core/display_ui.cpp/h`

**Responsibilities:**
- Create provisioning mode UI (simple text instructions)
- Create main UI (colorful tile grid, animated bar, FPS counter)
- Manage touch indicator dot

**APIs:**
```c
void display_ui_create_provisioning(lv_obj_t *scr);
void display_ui_create_main(lv_obj_t *scr, lv_obj_t **touch_dot,
                           volatile uint32_t *flush_count);
void display_ui_update_sensor(float temperature, float humidity, bool is_celsius);
```

**Provisioning UI:**
- Black background
- White text with connection instructions
- SSID: "HESTIA32"
- URL: "192.168.4.1"

**Main UI:**
- 4×6 grid of colorful rounded tiles (8 colors cycled)
- Animated white bar sliding horizontally (6-second loop)
- FPS counter (top-left corner)
- Touch indicator dot (16×16 magenta circle, follows touch)

---

### 6.6 Thermostat Module (Future Integration)

**Files:** `src/core/thermostat.c/h`

**Status:** Module complete, comprehensive tests pass, not integrated into main.c

**Responsibilities:**
- Multi-domain HVAC control (heating, cooling, fan, humidity, hot water)
- Multi-stage operation with time delays
- Hysteresis and minimum cycle time protection
- Fan coordination (pre-run/post-run)
- Open window detection and heating suspension
- Sensor failure safety
- Temperature unit conversion (Celsius/Fahrenheit)

**Architecture:**
```c
ThermostatConfig  → Configuration (setpoints, delays, enables)
ThermostatInput   → Sensor readings + time + user overrides
ThermostatState   → Internal state machine variables
ThermostatOutput  → GPIO control signals (heating, cooling, fan, etc.)
```

**Key Features:**

**1. Thermal Domain:**
- States: IDLE, HEATING, HEATING_STAGE2, COOLING, COOLING_STAGE2
- Stage 2 activation: Time delay (5-10 min) AND temperature deviation (>0.75°C)
- Minimum cycle time: 180 seconds (equipment protection)
- Hysteresis period: 300 seconds (prevents rapid switching)
- Deadbands: Comfort (0.5°C), Eco (1.5°C)

**2. Fan Domain:**
- Pre-run: Fan starts 30 seconds before thermal activation
- Post-run: Fan continues 60 seconds after thermal stops
- Manual override support
- Automatic coordination with thermal state

**3. Open Window Detection:**
- Monitors 3-sample temperature history
- Detects rapid drop (≥2°C over 3 minutes)
- Suspends heating for 15 minutes
- Prevents false triggers (gradual changes ignored)

**4. Humidity Domain:**
- Humidification or dehumidification modes
- 5% humidity deadband
- Independent from thermal operation

**5. Hot Water Domain:**
- Demand-driven (on/off control)
- No complex logic required

**APIs:**
```c
void thermostat_config_init(ThermostatConfig* config);
bool thermostat_config_validate(const ThermostatConfig* config);
void thermostat_state_init(ThermostatState* state, uint32_t now_seconds);
void thermostat_update(const ThermostatConfig* config,
                      const ThermostatInput* input,
                      ThermostatState* state,
                      ThermostatOutput* output);
float thermostat_c_to_f(float celsius);
float thermostat_f_to_c(float fahrenheit);
```

**Test Coverage:** 24 comprehensive tests including:
- Configuration validation
- Hysteresis protection
- Comfort/Eco deadbands
- Stage 2 activation logic
- Mutual exclusion (heating vs cooling)
- Sensor failure safety
- Fan timing (pre-run, post-run, manual override)
- HVAC system integration scenarios
- Open window detection
- Boost feature scenarios and edge cases
- 24-hour simulation

**Safety Features:**
- Immediate shutdown on sensor failure
- Heating and cooling mutual exclusion
- Equipment protection via minimum cycle times
- Configuration validation prevents invalid states

---

### 6.7 Boost Feature (Heating, Cooling, Hot Water)

**Status:** Implemented and Tested

**Description:**
The Boost feature allows temporary override of normal thermostat logic for rapid activation of heating, cooling, or hot water. When activated, the selected domain runs at maximum output (stage 1 only) for a configurable duration, after which normal operation resumes automatically. Each domain maintains independent boost state with per-domain timers.

**Implementation Details:**
- **API Functions:**
  - `thermostat_boost_activate(state, domain, now, duration_sec)` - Activate boost
  - `thermostat_boost_cancel(state, domain)` - Cancel active boost
  - `thermostat_boost_is_active(state, domain, now)` - Check boost status

- **Boost Behavior:**
  - Heating/Cooling: Forces stage 1 output ON; stage 2 always disabled during boost
  - Hot Water: Forces output ON regardless of demand signal
  - Duration: User-configurable per activation (in seconds)
  - Expiration: Automatic when current time ≥ boost_end_time
  - State tracking: boost_active flag, boost_end_time, boost_last_duration per domain

**Safety Features:**
1. **Sensor Failure Override:** Boost is disabled if sensors_valid = false
2. **Mutual Exclusion:** If both heating and cooling boosts are active, only the most recently activated boost runs (or both disabled if equal end times)
3. **Configuration Respect:** Boost won't activate if domain is disabled in config (heating_enabled, cooling_enabled, hot_water_enabled)
4. **Open Window Detection:** Heating boost is cancelled if open window is detected
5. **Normal Logic Resumption:** After boost expires or is cancelled, normal thermostat logic takes over immediately

**Test Coverage (24/24 tests pass):**

*Test 23 - Basic Functionality (5 scenarios):*
1. Boost activation for heating, cooling, and hot water
2. Override normal logic (forces output ON despite unfavorable conditions)
3. Stage 2 disabled during boost
4. Boost expiration after timeout
5. Manual boost cancellation

*Test 24 - Comprehensive Edge Cases (15 scenarios):*
1. Stage 2 config enabled but stays off during boost
2. Reactivating boost after expiration
3. Overlapping boost activations (updates end time)
4. Invalid domain names (graceful handling)
5. Boost with duration=0 (immediate expiration)
6. Sensor failure safety override
7. Normal logic resumption after expiration
8. Fan interaction during boost
9. Multiple simultaneous boosts (non-conflicting domains)
10. Mutual exclusion - heating vs cooling (latest wins)
11. Mutual exclusion - equal end times (both disabled)
12. Selective cancellation (cancel one, others remain active)
13. Exact boundary expiration (at end_time, not after)
14. Boost + open window detection (boost cancelled)
15. Boost respects domain enabled flags

**Dependencies:** Thermostat module (complete), UI integration (pending), NVS persistence (pending)

---

## 7. User Interface

### 7.1 Provisioning Mode Interface

**When:** First boot or after factory reset (no WiFi credentials)

**Display:**
```
┌─────────────────────────────────┐
│                                 │
│     WiFi Setup Required         │
│                                 │
│     Connect to: HESTIA32        │
│     Open: 192.168.4.1           │
│                                 │
│     Device will restart         │
│     after configuration         │
│                                 │
└─────────────────────────────────┘
```

**Web Interface:**
1. User connects phone/laptop to "HESTIA32" WiFi
2. Browser automatically redirects to 192.168.4.1 (captive portal)
3. Web form displays:
   - Scan button → Shows available WiFi networks
   - WiFi SSID input (pre-filled from scan)
   - WiFi Password input
   - Node Name input (optional, default: "Hestia32")
   - OTA Server URL (optional)
   - Save button
4. After save: Device restarts and connects to WiFi

### 7.2 Calibration Wizard Interface

**When:** First boot (no touch calibration in NVS)

**Display:**
```
┌─────────────────────────────────┐
│ Touch target 1/5 (60s remaining)│
│                                 │
│  +                              │  ← Crosshair (20px)
│                                 │
│                                 │
└─────────────────────────────────┘
```

**Sequence:**
1. Top-left corner (10, 10)
2. Top-right corner (310, 10)
3. Bottom-right corner (310, 470)
4. Bottom-left corner (10, 470)
5. Center (160, 240)

**Timeouts:**
- Overall: 60 seconds
- Per target: 15 seconds
- If timeout: Use default calibration (200-3900 range)

**User Feedback:**
- Countdown timer updates every second
- Target advances immediately on touch
- Visual feedback on touch detection

### 7.3 Main Application Interface

**When:** After successful WiFi connection and calibration

**Display Elements:**

1. **Tile Grid:** 4×6 colorful tiles (background pattern)
2. **Animated Bar:** White vertical bar sliding left-to-right (6s loop)
3. **FPS Counter:** Top-left corner, updates every second
4. **Touch Indicator:** 16×16 magenta circle with white border, follows touch

**Color Palette:**
- Background: #101820 (dark blue-gray)
- Tiles: 8 colors cycling (#2364AA, #3DA5D9, #73BFB8, #FEC601, #EA7317, #6C2E2F, #8A2BE2, #2ECC71)
- Touch dot: #FF00FF (magenta)

**Performance:**
- Target: 25+ FPS
- LVGL task runs at 100Hz (10ms period)
- Flush callback triggered by LVGL as needed

---

## 8. Data Management

### 8.1 NVS (Non-Volatile Storage) Layout

**Partition:** 24KB at offset 0x9000

**Namespaces:**

| Namespace | Keys | Purpose |
|---|---|---|
| `wifi_config` | ssid, password, node_name, ota_url | WiFi provisioning data |
| `touch_cal` | x_min, x_max, y_min, y_max, swap_xy, flip_x, flip_y | Touch calibration |

**Data Types:**
- Strings: null-terminated, max 128 bytes
- Integers: uint16_t (calibration), uint8_t (boolean flags)

### 8.2 Partition Table

**File:** `partitions_two_ota.csv`

```
# Name      Type    SubType   Offset   Size     Flags
nvs         data    nvs                0x6000   (24KB)
otadata     data    ota                0x2000   (8KB)
phy_init    data    phy                0x1000   (4KB)
ota_0       app     ota_0              0x1D0000 (1.8MB)
ota_1       app     ota_1              0x1D0000 (1.8MB)
```

**Total Flash Required:** 3.76MB (fits in 4MB flash)

### 8.3 Data Persistence Strategy

**WiFi Credentials:**
- Saved immediately after provisioning form submission
- Loaded on boot if device is provisioned
- Erased on factory reset

**Touch Calibration:**
- Saved immediately after calibration wizard completes
- Loaded on boot to skip recalibration
- Erased on factory reset

**OTA State:**
- Managed automatically by ESP-IDF OTA library
- Tracks active partition (ota_0 or ota_1)
- Handles rollback on boot failure

---

## 9. Security Considerations

### 9.1 Current Security Posture

**Implemented:**
- HTTPS OTA downloads (SSL/TLS encryption)
- No hardcoded WiFi credentials
- Provisioning AP requires physical proximity

**Limitations (Development Mode):**
1. Provisioning AP is **open** (no password)
2. No firmware signing/verification
3. No certificate validation for OTA server
4. HTTP provisioning interface (not HTTPS)
5. No authentication on web interface

### 9.2 Production Security Recommendations

**High Priority:**
1. **Enable provisioning AP password**
   - Set `PROV_AP_PASSWORD` to strong passphrase
   - Display password on device screen or label

2. **Implement HTTPS for provisioning**
   - Use self-signed certificate or Let's Encrypt
   - Prevents credential interception

3. **Add OTA server certificate validation**
   - Pin server certificate or use CA bundle
   - Prevents man-in-the-middle attacks

4. **Enable Flash Encryption**
   - Encrypt firmware and NVS data at rest
   - Protects credentials if device is stolen

**Medium Priority:**

5. **Add web interface authentication**
   - Username/password for provisioning
   - Session tokens to prevent CSRF

6. **Implement rate limiting**
   - Limit failed WiFi connection attempts
   - Prevent brute-force attacks

7. **Add audit logging**
   - Log OTA updates, factory resets, provisioning events
   - Store in external server or encrypted local storage

### 9.3 Security Testing Checklist

- [ ] Test provisioning with special characters in password
- [ ] Test factory reset completely erases credentials
- [ ] Verify bootloader can't be overwritten
- [ ] Test rollback after OTA failure

---

## 10. Development Environment

### 10.1 Prerequisites

**Common:**
- Git with submodule support
- Python 3.8+
- USB drivers for ESP32 board

**For ESP32 (PlatformIO):**
- [PlatformIO Core](https://platformio.org/) or PlatformIO IDE
- GCC toolchain (installed by PlatformIO)

**For ESP32-C5 (ESP-IDF):**
- ESP-IDF v5.5.2 or later (C5 support)
- CMake 3.16+
- Ninja build system
- RISC-V toolchain (installed by ESP-IDF)

**For Testing (Native):**
- GCC or Clang with C11 support
- Make (optional)

### 10.2 ESP-IDF Setup (ESP32-C5)

**One-time installation:**

```bash
# Clone ESP-IDF v5.5
cd ~/esp
git clone --recursive --branch v5.5.2 \
    https://github.com/espressif/esp-idf.git esp-idf-v5.5

# Install tools for ESP32-C5
cd ~/esp/esp-idf-v5.5
./install.sh esp32c5
```

**Per-session environment setup:**

```bash
# Source ESP-IDF environment
source ~/esp/esp-idf-v5.5/export.sh

# Or use project script
./setup-c5.sh

# Configure target (first time only)
idf.py set-target esp32c5
```

### 10.3 PlatformIO Setup (ESP32)

**Installation:**

```bash
# Install PlatformIO CLI
pip install platformio

# Or use PlatformIO IDE (VS Code extension)
```

**Configuration:** `platformio.ini`
```ini
[env:nodemcu-32s]
platform = espressif32
board = nodemcu-32s
framework = espidf
monitor_speed = 115200
board_build.partitions = partitions_two_ota.csv
```

### 10.4 Cloning the Repository

**Important:** Project uses LVGL as a git submodule

```bash
# Clone with submodules
git clone --recursive https://github.com/MakeOpenStuff/hestia32.git
cd hestia32

# If already cloned without --recursive:
git submodule update --init --recursive
```

### 10.5 VS Code Integration

**Recommended Extensions:**
- C/C++ (Microsoft)
- ESP-IDF (Espressif) for C5 development
- PlatformIO IDE for ESP32 development

**Tasks:** Available via [Tasks.json](./vscode/tasks.json)
- ESP-IDF: Build
- ESP-IDF: Flash
- ESP-IDF: Monitor
- ESP-IDF: Build and Flash
- ESP-IDF: Build, Flash and Monitor
- ESP-IDF: Clean
- ESP-IDF: Menuconfig

---

## 11. Build and Deployment

### 11.1 Protocol Selection

Hestia32 supports multiple communication protocols for smart home integration. Select the desired protocol when building:

#### Available Protocols

| Protocol | Status | Description |
|---|---|---|
| **MQTT** | Fully Implemented | WiFi-based MQTT communication with Home Assistant, OpenHAB, etc. |
| **Zigbee** | Placeholder | Future Zigbee 3.0 support (stub implementation only) |
| **Matter** | Placeholder | Future Matter protocol support (stub implementation only) |

#### Building with Specific Protocol

**Method 1: Using sdkconfig presets (recommended)**

```bash
# MQTT Protocol (default)
idf.py -D SDKCONFIG_DEFAULTS=sdkconfig.mqtt build

# Zigbee Protocol (not yet implemented)
idf.py -D SDKCONFIG_DEFAULTS=sdkconfig.zigbee build

# Matter Protocol (not yet implemented)
idf.py -D SDKCONFIG_DEFAULTS=sdkconfig.matter build
```

**Method 2: Interactive configuration**

```bash
idf.py menuconfig
# Navigate to: Hestia32 Configuration → Communication Protocol
# Select: MQTT over WiFi / Zigbee / Matter
```

**Method 3: Check current protocol**

```bash
grep "CONFIG_PROTOCOL_" sdkconfig
```

Expected output for MQTT:
```
CONFIG_PROTOCOL_MQTT=y
# CONFIG_PROTOCOL_ZIGBEE is not set
# CONFIG_PROTOCOL_MATTER is not set
```

#### Protocol-Specific Build Components

**MQTT Build:**
- `protocols/mqtt/mqtt_protocol.c` - MQTT protocol implementation
- `protocols/mqtt/wifi_manager.c` - WiFi connection management
- `protocols/mqtt/wifi_provisioning.c` - AP-mode provisioning
- `protocols/mqtt/ota_manager.c` - HTTPS OTA updates
- WiFi stack enabled (~1.26 MB binary)

**Zigbee Build (future):**
- `protocols/zigbee/protocol_zigbee.c` - Zigbee protocol (stub)
- ESP Zigbee SDK integration (planned)
- Estimated size: ~800 KB

**Matter Build (future):**
- `protocols/matter/protocol_matter.c` - Matter protocol (stub)
- ESP Matter SDK integration (planned)
- Estimated size: ~1.5 MB

#### Clean Build After Protocol Change

When switching protocols, perform a clean reconfigure:

```bash
idf.py fullclean
idf.py -D SDKCONFIG_DEFAULTS=sdkconfig.mqtt reconfigure
idf.py build
```

### 11.2 Building for ESP32-C5

```bash
# Set up environment
source ~/esp/esp-idf-v5.5/export.sh

# Build firmware (uses default protocol from sdkconfig)
idf.py build

# Or specify protocol explicitly
idf.py -D SDKCONFIG_DEFAULTS=sdkconfig.mqtt build

# View build output
ls build/hestia32.bin
```

**Build outputs:**
- `build/hestia32.bin` - Application firmware
- `build/bootloader/bootloader.bin` - Bootloader
- `build/partition_table/partition-table.bin` - Partition table
- `build/ota_data_initial.bin` - OTA data initialization

### 11.3 Flashing to ESP32-C5

**Full flash (first time):**

```bash
idf.py -p /dev/ttyACM0 flash
```

**Application only (faster):**

```bash
idf.py -p /dev/ttyACM0 app-flash
```

**Erase everything:**

```bash
idf.py -p /dev/ttyACM0 erase-flash
```

**Serial port detection:**
- Linux: `/dev/ttyUSB0` or `/dev/ttyACM0`
- macOS: `/dev/cu.usbserial-*`
- Windows: `COM3`, `COM4`, etc.

### 11.3 Building for ESP32 (PlatformIO)

```bash
# Build
pio run -e nodemcu-32s

# Upload
pio run -e nodemcu-32s -t upload

# Monitor
pio device monitor
```

### 11.4 Monitoring Serial Output

**ESP-IDF:**

```bash
idf.py -p /dev/ttyACM0 monitor

# Or combined flash + monitor:
idf.py -p /dev/ttyACM0 flash monitor
```

**PlatformIO:**

```bash
pio device monitor -b 115200
```

**Expected output on first boot:**

```
I (123) main: Hestia32 ESP32-C5 Application
I (125) main: Firmware Version: 0.8.4
I (130) main: NVS initialized
I (135) main: Factory reset: hold BOOT for 5 seconds while running
I (145) display: No calibration found - running wizard first
I (150) display: Starting touch calibration (60 second timeout)
I (155) display: Touch target 1/5 (60s remaining)
...
```

---

## 12. Testing Strategy

### 12.1 Unit Testing (Thermostat Module)

**Location:** `tests/test_thermostat.c`

**Execution:**

```bash
# Using Makefile
make test

# Manual
gcc -Wall -Wextra -std=c11 -I. src/core/thermostat.c tests/test_thermostat.c -o test_thermostat -lm
./test_thermostat
```

**Test Suite:** 24 comprehensive tests

1. Configuration validation
2. Hysteresis protection (prevents rapid switching)
3. Comfort deadband (±0.5°C)
4. Eco deadband (±1.5°C)
5. Stage 2 heating (10min delay + 0.75°C deviation)
6. Stage 2 cooling (5min delay + 0.75°C deviation)
7. Heating/cooling mutual exclusion
8. Sensor failure safety (immediate shutdown)
9. Temperature unit conversion
10. Fan pre-run (30s before thermal)
11. Fan post-run (60s after thermal)
12. Fan manual override
13. Hysteresis + HVAC (fan coordination)
14. Comfort deadband + HVAC
15. Eco deadband + HVAC
16. Stage 2 heating + HVAC
17. Stage 2 cooling + HVAC
18. Mutual exclusion + HVAC
19. Sensor failure + HVAC
20. Open window detection (2°C drop over 3 minutes)
21. Open window false positive prevention
22. 24-hour heating cycle simulation
23. Boost functionality
24. Boost edge cases

**Output:**
```
=== TEST 1: Configuration Validation ===
Testing: thermostat_config_validate() with various invalid configs
✓ PASSED: Configuration Validation

=== TEST 24: Boost Feature - Comprehensive Edge Cases ===
...
✓ PASSED: Boost Feature - Comprehensive Edge Cases

=== SUMMARY ===
Total Tests: 24
Passed: 24
Failed: 0
Success Rate: 100.00%
```

### 12.2 Integration Testing

**Manual test procedures:**

**Test 1: WiFi Provisioning**
1. Flash firmware with erased NVS
2. Verify AP "HESTIA32" appears
3. Connect to AP
4. Verify captive portal redirect
5. Complete provisioning form
6. Verify device restarts and connects
7. Check serial logs for WiFi IP address

**Test 2: Touch Calibration**
1. Flash firmware with erased calibration
2. Verify calibration wizard appears
3. Touch all 5 targets
4. Verify UI responds to touch correctly
5. Factory reset and repeat
6. Verify calibration persists after reboot

**Test 3: Factory Reset**
1. Provision device with WiFi
2. Calibrate touchscreen
3. Keep device running in normal mode
4. Hold BOOT button for 5+ seconds
5. Release after confirmation message
6. Verify "Factory reset confirmed!" in logs
7. Verify device enters provisioning mode
8. Verify calibration wizard runs

**Test 4: OTA Update**
1. Build firmware v0.8.4
2. Flash to device
3. Build firmware v0.8.5 (increment APP_VERSION)
4. Upload v0.8.5 to HTTPS server
5. Configure OTA URL via provisioning
6. Trigger update (manual or automatic)
7. Verify update completes
8. Verify device boots v0.8.5
9. Check logs for "OTA update successful"

**Test 5: Display Performance**
1. Flash firmware
2. Complete setup
3. Verify main UI renders
4. Check FPS counter (should be 25+)
5. Test touch responsiveness (dot follows)
6. Verify animated bar moves smoothly
7. Run for 1 hour, check for crashes/leaks

### 12.3 Hardware Validation

**Electrical tests:**
- [ ] Verify 3.3V on display VCC
- [ ] Check SPI signals with logic analyzer (MOSI, SCLK, CS, DC)
- [ ] Measure backlight PWM signal (5kHz)
- [ ] Test touch IRQ goes low on press
- [ ] Verify MISO line is connected only to touch controller

**Physical tests:**
- [ ] Touch all corners and center
- [ ] Verify no dead zones on display
- [ ] Test at different viewing angles (IPS should be uniform)
- [ ] Check backlight uniformity
- [ ] Test button press responsiveness

### 12.4 Stress Testing

**Network stress:**
- Disconnect WiFi during operation
- Verify auto-reconnect works
- Test provisioning with weak signal
- Test with 50+ WiFi networks visible

**Power stress:**
- Test rapid power cycles
- Verify NVS data integrity
- Test brownout protection
- Measure power consumption

**Memory stress:**
- Run device for 24+ hours
- Monitor free heap via logs
- Check for memory leaks
- Verify no task stack overflows

### 12.5 Test Automation (Future)

**Recommended framework:** Unity + CMock

**Automated tests to implement:**
1. WiFi provisioning API mocking
2. NVS read/write simulation
3. Display callback verification
4. OTA state machine testing
5. Touch calibration algorithm validation

---

## 13. Future Roadmap

### 13.1 Short-term (Next Release - v1.1.0)

**Thermostat Integration:**
- [ ] Wire thermostat module into main.c
- [x] Add temperature/humidity sensor support (SHT45 - completed)
- [x] Temperature unit preference (Celsius/Fahrenheit) stored in NVS
- [ ] Create settings UI for setpoint adjustment
- [ ] Add relay control for heating/cooling outputs
- [ ] Display current temperature and mode on screen

**Security Enhancements:**
- [ ] Add password to provisioning AP
- [ ] Enable HTTPS for web provisioning
- [ ] Add firmware version display in UI

**UI Improvements:**
- [ ] Design thermostat control screen
- [ ] Add WiFi status indicator
- [ ] Design settings control
- [ ] Show current time (NTP sync)
- [ ] Add screen brightness adjustment

### 13.2 Medium-term (v1.2.0 - v1.3.0)

**Advanced Thermostat Features:**
- [ ] Schedule programming (7-day schedule)
- [ ] Remote control via MQTT or HTTP API
- [ ] Historical data logging (temperature trends)
- [ ] Vacation mode (extended away settings)
- [ ] Smart learning (adaptive scheduling)

**Connectivity:**
- [ ] MQTT support (Home Assistant and OpenHAB integration with auto discovery)
- [ ] RESTful API for remote control
- [ ] WebSocket for real-time updates
- [ ] Bluetooth provisioning alternative
- [ ] Zigbee support
- [ ] Thread support

**Hardware Expansion:**
- [ ] Support for additional sensors (air quality, motion)
- [ ] External relay board compatibility
- [ ] Support for larger displays (480×800)

### 13.3 Long-term (v2.0.0+)

**Machine Learning:**
- [ ] Occupancy detection
- [ ] Predictive heating/cooling
- [ ] Anomaly detection (equipment failure)
- [ ] Energy optimization recommendations

**Professional Features:**
- [ ] Multi-zone support (up to 8 zones)
- [ ] Commercial HVAC compatibility
- [ ] BACnet/Modbus protocol support
- [ ] Professional installer mode

---

## 14. Appendices

### Appendix A: Acronyms and Abbreviations

| Acronym | Definition |
|---|---|
| AP | Access Point |
| BACnet | Building Automation and Control Networks |
| CS | Chip Select |
| DC | Data/Command (Display) |
| DHCP | Dynamic Host Configuration Protocol |
| DNS | Domain Name System |
| ESP-IDF | Espressif IoT Development Framework |
| FPS | Frames Per Second |
| FSD | Functional Specification Document |
| GPIO | General Purpose Input/Output |
| HTTPS | Hypertext Transfer Protocol Secure |
| HVAC | Heating, Ventilation, and Air Conditioning |
| IDF | IoT Development Framework |
| ILI9488 | Display controller IC |
| IPS | In-Plane Switching (LCD technology) |
| IRQ | Interrupt Request |
| JSON | JavaScript Object Notation |
| LEDC | LED Controller (PWM) |
| LVGL | Light and Versatile Graphics Library |
| MISO | Master In, Slave Out (SPI) |
| MOSI | Master Out, Slave In (SPI) |
| MQTT | Message Queuing Telemetry Transport |
| NTP | Network Time Protocol |
| NVS | Non-Volatile Storage |
| OTA | Over-The-Air |
| PHY | Physical Layer |
| PWM | Pulse Width Modulation |
| RGB | Red, Green, Blue |
| RISC-V | Reduced Instruction Set Computer - V |
| RST | Reset |
| SCLK | Serial Clock (SPI) |
| SPI | Serial Peripheral Interface |
| SSID | Service Set Identifier (WiFi network name) |
| TLS | Transport Layer Security |
| UART | Universal Asynchronous Receiver/Transmitter |
| UI | User Interface |
| URL | Uniform Resource Locator |
| USB | Universal Serial Bus |
| XPT2046 | Touch controller IC |

### Appendix B: File Structure

```
hestia32/
├── src/                          # Source code
│   ├── main.c                    # Application entry point
│   ├── CMakeLists.txt            # Build configuration
│   ├── Kconfig.projbuild         # Board/protocol selection
│   ├── core/                     # Protocol-agnostic core modules
│   │   ├── core_config.h
│   │   ├── display_config.h
│   │   ├── display_manager.cpp/h
│   │   ├── display_ui.cpp/h
│   │   ├── protocol_manager.c/h
│   │   ├── relay_manager.c/h
│   │   ├── sensor_sht45.c/h
│   │   ├── thermostat.c/h
│   │   └── user_settings.c/h
│   └── protocols/                # Protocol implementations
│       ├── protocol_interface.h
│       ├── mqtt/                 # Implemented stack
│       ├── zigbee/               # Stub
│       └── matter/               # Stub
├── tests/                        # Test suite and diagnostics
│   ├── power_test.c/h
│   ├── sensor_test.c/h
│   ├── rgb_led_test.c/h
│   ├── i2c_scanner.c/h
│   ├── test_thermostat.c
│   ├── test_blink/               # Standalone ESP-IDF test app
│   └── test_i2c_scanner/         # Standalone ESP-IDF test app
├── components/                   # External components
│   ├── esp_lcd_ili9488/          # ILI9488 display driver
│   └── lvgl/                     # LVGL library (submodule)
├── build/                        # Build output (generated)
├── CMakeLists.txt                # Top-level ESP-IDF config
├── platformio.ini                # PlatformIO configuration
├── partitions_two_ota.csv        # Partition table
├── sdkconfig.defaults            # ESP-IDF default settings
├── setup-c5.sh                   # ESP32-C5 environment script
├── Makefile                      # Test build automation
├── README.md                     # Project documentation
├── QUICK_START.md                # Quick reference guide
├── WIRING.md                     # Hardware wiring guide
└── Hestia32-FSD.md        # This document
```

### Appendix C: Key Configuration Parameters

**File:** `src/core/core_config.h`

| Parameter | Default Value | Description |
|---|---|---|
| PROV_AP_SSID | "HESTIA32" | Provisioning AP name |
| PROV_AP_PASSWORD | "" | AP password (empty = open) |
| FACTORY_RESET_GPIO | 28 (C5) / 0 (ESP32) | BOOT button GPIO |
| WIFI_MAX_RETRY | 5 | WiFi connection retry count |
| OTA_CHECK_INTERVAL_MS | 300000 | OTA check interval (5 min) |
| APP_VERSION | "0.8.4" | Firmware version string |
| LOOP_DELAY_MS | 10000 | Main loop delay (deprecated) |

**File:** `src/core/display_config.h`

| Parameter | Value | Description |
|---|---|---|
| TFT_WIDTH | 320 | Display width (pixels) |
| TFT_HEIGHT | 480 | Display height (pixels) |
| LCD_PIXEL_CLOCK_HZ | 20MHz (DevKit) / 8MHz (XIAO) | SPI clock (display) |
| TOUCH_SPEED | 1MHz | SPI clock (touch) |
| LVGL_TICK_PERIOD_MS | 2 | LVGL tick rate |
| LVGL_BUFFER_HEIGHT | 80 (DevKit) / 40 (XIAO) | Line buffer height |

### Appendix D: Useful Commands Reference

**ESP-IDF (ESP32-C5):**

```bash
# Environment setup
source ~/esp/esp-idf-v5.5/export.sh

# Build commands
idf.py build                    # Build firmware
idf.py clean                    # Clean build
idf.py fullclean                # Full clean (includes config)
idf.py menuconfig               # Configuration menu

# Flashing
idf.py -p PORT flash            # Flash all
idf.py -p PORT app-flash        # Flash app only
idf.py -p PORT erase-flash      # Erase everything

# Monitoring
idf.py -p PORT monitor          # Serial monitor
idf.py -p PORT flash monitor    # Flash + monitor

# Size analysis
idf.py size                     # Show binary sizes
idf.py size-components          # Size by component
idf.py size-files               # Size by file
```

**PlatformIO (ESP32):**

```bash
# Build commands
pio run -e nodemcu-32s                    # Build firmware
pio run -e nodemcu-32s -t clean           # Clean build

# Flashing
pio run -e nodemcu-32s -t upload          # Upload firmware
pio run -e nodemcu-32s -t erase           # Erase flash

# Monitoring
pio device monitor -b 115200              # Serial monitor
pio run -e nodemcu-32s -t upload -t monitor  # Upload + monitor

# Dependencies
pio lib install                           # Install libraries
```

**Testing:**

```bash
# Thermostat tests
make test                                 # Run all tests
make clean                                # Clean test build

# Manual test build
gcc -Wall -Wextra -std=c11 -I. src/core/thermostat.c tests/test_thermostat.c -o test_thermostat -lm
./test_thermostat
```

### Appendix E: Troubleshooting Guide

**Problem:** Device won't enter provisioning mode

**Solution:**
1. Check serial logs for "Device provisioned" message
2. Perform factory reset (hold BOOT 5 seconds)
3. Verify NVS partition is not corrupted: `idf.py erase-flash`

---

**Problem:** Touch not responding or inaccurate

**Solution:**
1. Verify MISO line connected only to touch (not display)
2. Run factory reset to trigger recalibration
3. Check touch IRQ pin goes low on press
4. Verify SPI signals with logic analyzer

---

**Problem:** Display shows garbage or wrong colors

**Solution:**
1. Check VCC is 3.3V (not 5V)
2. Verify SPI connections (MOSI, SCLK, CS, DC, RST)
3. Add 100µF capacitor near display VCC
4. Reduce SPI clock speed (change `LCD_PIXEL_CLOCK_HZ`)

---

**Problem:** WiFi won't connect after provisioning

**Solution:**
1. Check WiFi network is 2.4GHz (ESP32 doesn't support 5GHz)
2. Verify password is correct (check for special characters)
3. Check router allows new device connections
4. Try factory reset and re-provision
5. Check serial logs for connection error codes

---

**Problem:** OTA update fails

**Solution:**
1. Verify OTA URL is accessible (try in browser)
2. Check server uses HTTPS (not HTTP)
3. Verify firmware binary is valid (`idf.py build`)
4. Check available space in target partition
5. Monitor serial logs for specific error codes

---

**Problem:** Device crashes or reboots randomly

**Solution:**
1. Check power supply is stable (min 500mA)
2. Monitor heap usage via serial logs
3. Look for task stack overflows
4. Run in debug mode with panic handler enabled
5. Test with minimal UI (comment out animations)

---

**Problem:** Factory reset not working

**Solution:**
1. Verify BOOT button GPIO matches hardware (28 for C5, 0 for ESP32)
2. Check button actually pulls GPIO low (test with multimeter)
3. Hold button while firmware is running (not only during power-on)
4. Increase hold time (currently 5 seconds)
5. Check serial logs for runtime hold progress/confirmation

---

### Appendix F: References and Resources

**ESP-IDF Documentation:**
- Official Docs: https://docs.espressif.com/projects/esp-idf/en/latest/
- API Reference: https://docs.espressif.com/projects/esp-idf/en/latest/api-reference/
- ESP32-C5 Datasheet: https://www.espressif.com/en/products/socs/esp32-c5

**LVGL Documentation:**
- Official Site: https://lvgl.io/
- Documentation: https://docs.lvgl.io/
- GitHub: https://github.com/lvgl/lvgl

**ILI9488 Resources:**
- Datasheet: ILI9488 V0.2 2014/10/08
- Driver: https://github.com/espressif/esp-iot-solution/tree/master/components/lcd/ili9488

**XPT2046 Resources:**
- Datasheet: XPT2046 Touch Screen Controller
- Arduino Library: https://github.com/PaulStoffregen/XPT2046_Touchscreen

**PlatformIO:**
- Official Site: https://platformio.org/
- ESP32 Platform: https://docs.platformio.org/en/latest/platforms/espressif32.html

**Community Resources:**
- ESP32 Forum: https://esp32.com/
- LVGL Forum: https://forum.lvgl.io/
- GitHub Issues: https://github.com/MakeOpenStuff/hestia32/issues

---

## Document Revision History

| Version | Date | Author | Changes |
|---|---|---|---|
| 1.0 | Initial | Original | Initial FSD with comprehensive analysis, actual implementation details, thermostat specification, testing strategy |
| 1.1 | 2026-04-23 | Updated | Synced with current code layout (`src/core` + `src/protocols`), board-specific pin mappings, runtime factory reset behavior, 24-test thermostat suite, and current ESP-IDF command usage |
| 1.2 | 2026-04-25 | Release Prep | Bumped firmware to v0.9.0 for public release; PCB v1.2 finalized; README expanded with HVAC/protocol/variant details |

---

**End of Document**

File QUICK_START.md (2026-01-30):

# ESP32 OTA Project - Quick Reference

## Project Structure (Simplified)

```
hestia32/
├── src/
│   ├── main.c                   # Main application entry point
│   ├── config.h                 # Provisioning AP & OTA configuration
│   ├── wifi_provisioning.c/h    # WiFi provisioning portal
│   ├── wifi_manager.c/h         # WiFi connection module
│   ├── ota_manager.c/h          # OTA update module
│   └── CMakeLists.txt           # ESP-IDF build config
├── platformio.ini               # PlatformIO configuration
├── partitions_two_ota.csv       # Dual OTA partition table
└── README.md                    # Full documentation

```

## What's New

### WiFi Provisioning Portal (Latest)
- **No hardcoded WiFi credentials** - Configure via web interface
- **Captive portal** - Access http://192.168.4.1 when connected to ESP32-Setup AP
- **NVS storage** - Credentials saved permanently
- **Extra settings** - Configure OTA server URL and device name
- **Factory reset** - Can reset and reconfigure anytime

### Previous Features
- **WiFi Manager Module**: Complete WiFi connection handling
- **OTA Manager Module**: Working HTTPS OTA implementation
- **Configuration Header**: Centralized settings
- **Clean Main Loop**: FreeRTOS-based, no watchdog issues
- **Simplified Documentation**: Focus on what's actually implemented

## Quick Start Commands

```bash
# NO CONFIGURATION NEEDED - Just flash and configure via web!

# Build and upload
pio run -t upload

# Monitor serial output to see provisioning instructions
pio device monitor
```

## First Time Setup (WiFi Provisioning)

1. **Flash the firmware** (see commands above)

2. **Device creates WiFi AP**:
   - SSID: `ESP32-Setup`
   - Password: `12345678`

3. **Connect to the AP** with your phone/laptop

4. **Open browser** and go to: `http://192.168.4.1`

5. **Fill in the form**:
   - WiFi SSID (your network)
   - WiFi Password
   - OTA Server URL (optional)
   - Node Name (optional)

6. **Click Save** - Device restarts and connects to your WiFi!

## Factory Reset / Reconfigure

```bash
# Option 1: Erase and reflash
pio run -t erase
pio run -t upload

# Option 2: Add reset button (future feature)
# Will trigger wifi_prov_reset() + esp_restart()
```

## Next Steps

1. **Flash firmware** - `pio run -t upload`
2. **Connect to ESP32-Setup WiFi** and configure at http://192.168.4.1
3. **Device connects to your WiFi** automatically
4. **Set up an OTA server** (see README.md)
5. **Test OTA updates** by incrementing version and uncommenting OTA check
6. **Add security** for production (HTTPS certificates, firmware signing)

## Key Features

- [x] **WiFi Provisioning Portal** - No hardcoded credentials!
- [x] **NVS Storage** - Settings persist across reboots
- [x] **Clean, modular code** structure
- [x] Proper error handling
- [x] WiFi auto-reconnect
- [x] OTA rollback protection
- [x] No watchdog timer issues
- [x] Ready for production (with security additions)
- [x] **Boost Feature** - Temporarily override heating, cooling, or hot water for a user-defined countdown. Only stage 1 is activated during boost. Each domain has its own adjustable timer.
## Using the Boost Feature

To activate Boost for heating, cooling, or hot water:

1. Use the UI or physical controls to select the domain (heating, cooling, hot water).
2. Set the desired countdown duration. The last-used duration is remembered per domain and can be adjusted.
3. During Boost, only stage 1 is activated for heating/cooling. After the countdown, normal operation resumes.

Refer to the README.md for more details.

## Configuration Structure

```c
// Stored in NVS, configurable via web portal:
typedef struct {
    char ssid[32];           // WiFi network name
    char password[64];       // WiFi password
    char server_url[128];    // OTA server URL (optional)
    char node_name[32];      // Device name (optional)
    bool provisioned;        // Provisioning status flag
} wifi_config_data_t;
```

## Documentation

- **README.md** - Full implementation guide and documentation
- **partitions_two_ota.csv** - Partition table for dual OTA slots

## Build Status

**Last Build**: Success
**RAM Usage**: 9.6% (31,504 / 327,680 bytes)
**Flash Usage**: 72.5% (759,917 / 1,048,576 bytes)

## Notes

- Uses ESP-IDF framework version 5.1.2
- Supports OTA updates via HTTPS
- Dual partition scheme allows safe rollback
- WiFi connection with retry logic
- Periodic OTA checks (configurable interval)

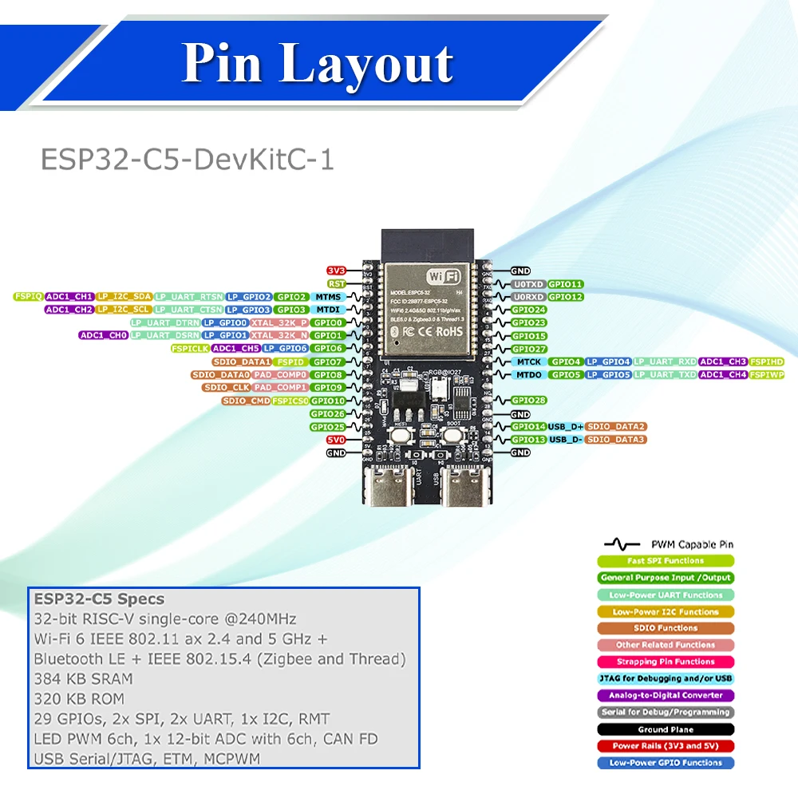
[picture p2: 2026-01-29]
docs/esp32-c5/pinout.jpg

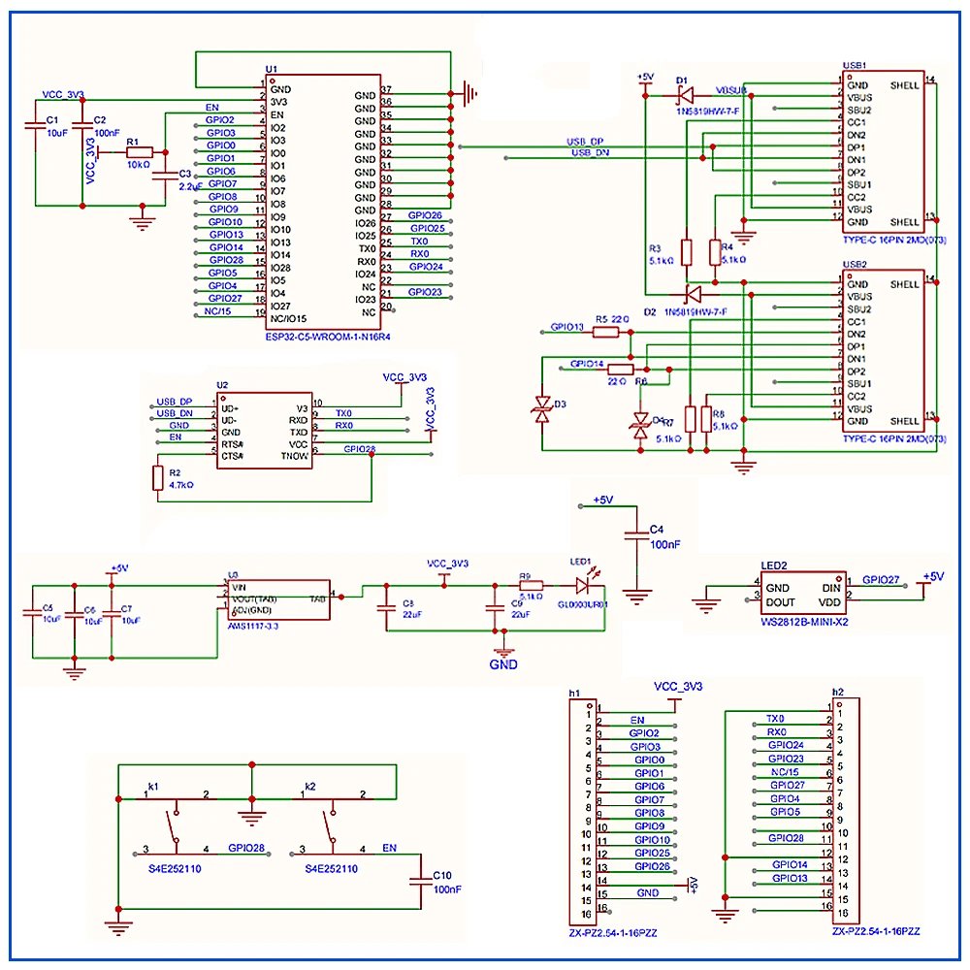
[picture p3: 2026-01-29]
docs/esp32-c5/schematic.jpg

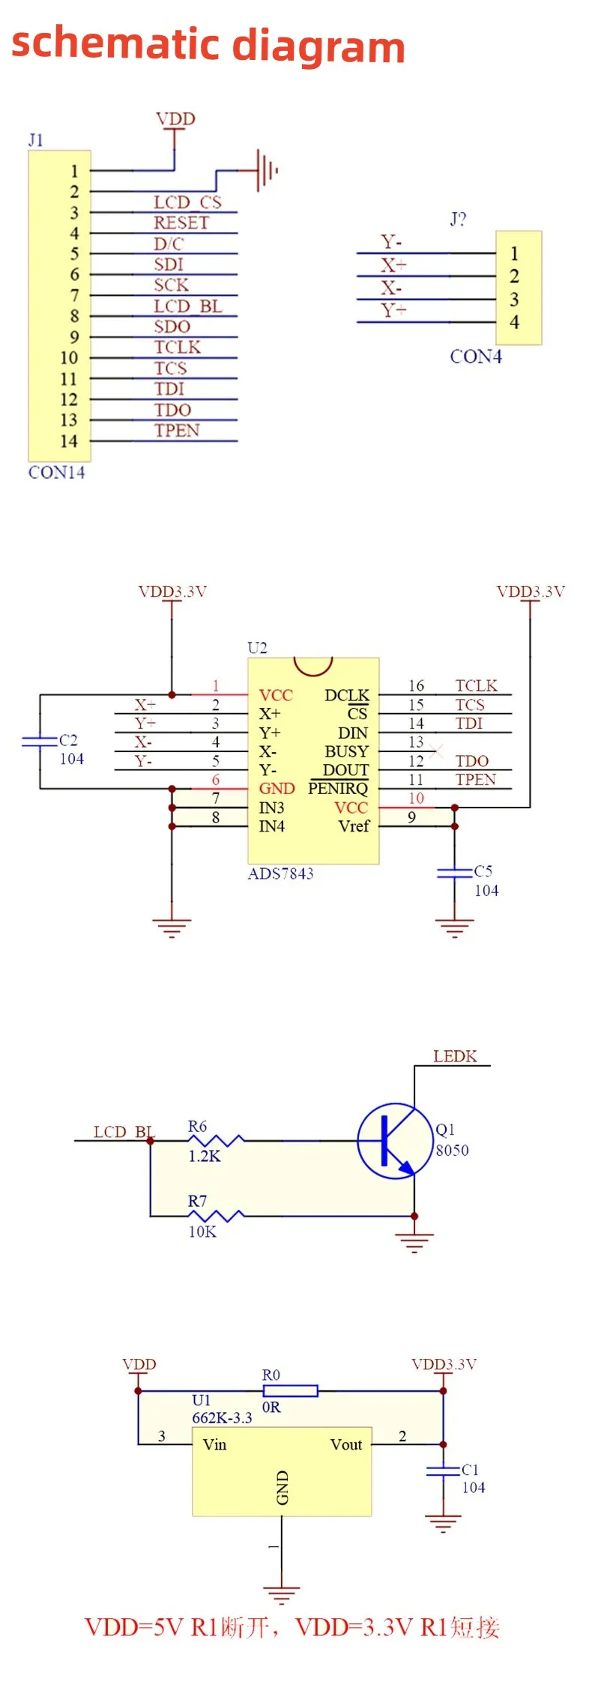
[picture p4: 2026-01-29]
docs/display/schematic.jpg

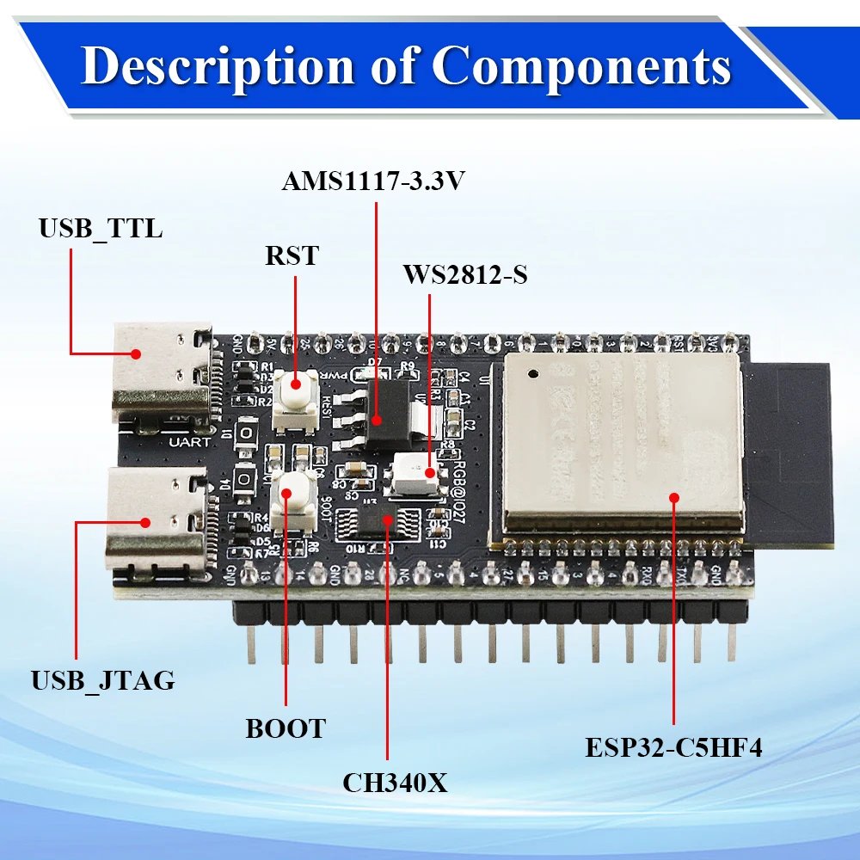
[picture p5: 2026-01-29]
docs/esp32-c5/locations.jpg

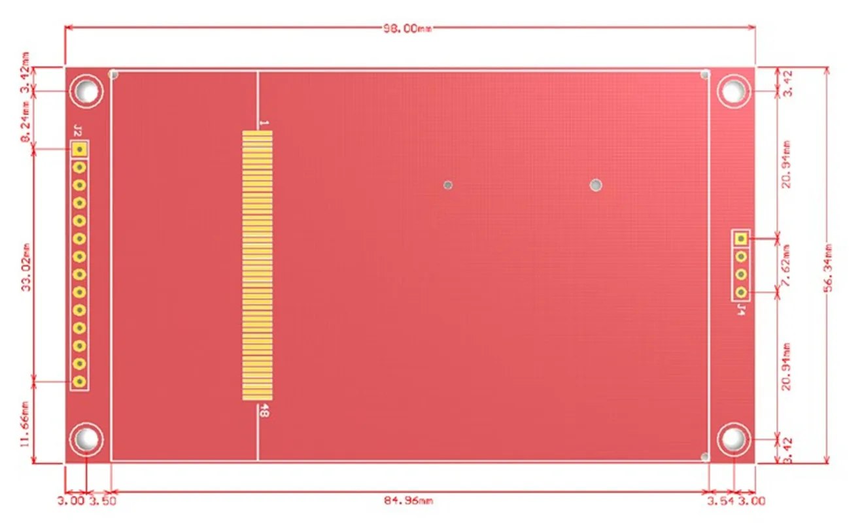
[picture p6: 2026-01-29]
docs/display/dimensions.jpg

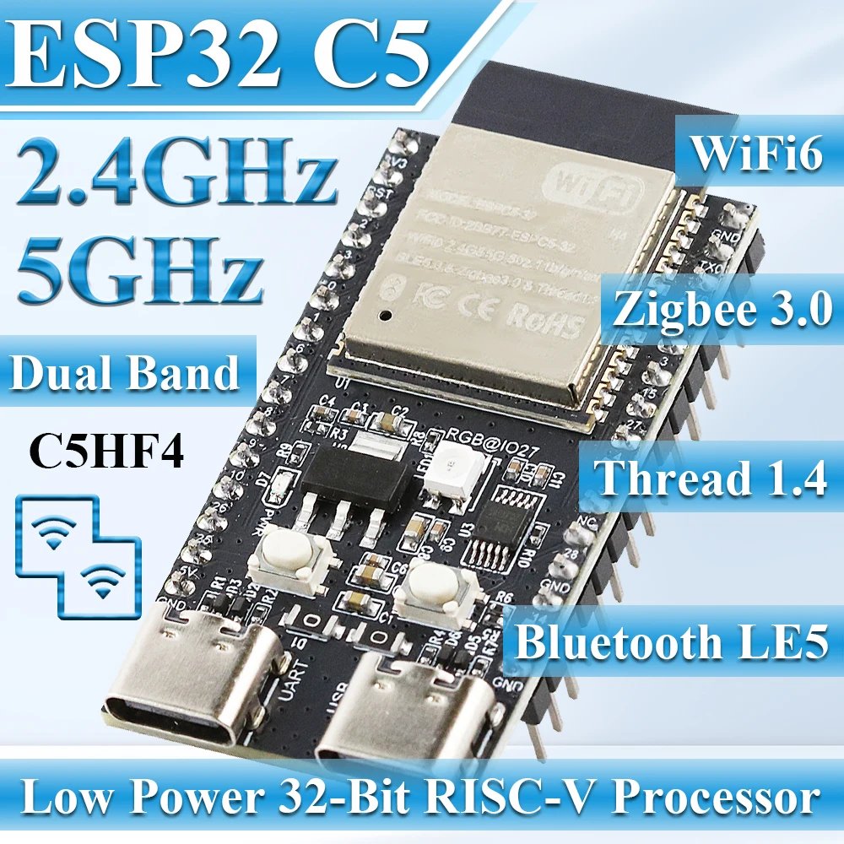
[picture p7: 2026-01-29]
docs/esp32-c5/features.jpg

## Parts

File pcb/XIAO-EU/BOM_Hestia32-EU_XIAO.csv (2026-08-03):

ID | Name | Designator | Footprint | Quantity | Manufacturer Part | Manufacturer | Supplier | Supplier Part | Price
1 | 220uF | C7 | CAP-TH_BD6.3-P2.50-D1.0-FD | 1 | ZF227M010E07RR0VH4FP0 | Chengx(承兴) | LCSC | C43331 | 0.023
2 | 47uF | C8 | C1206 | 1 | C3216X5R1A476MTJ00N | TDK | LCSC | C342308 | 0.296
3 | Common Mode Choke 10-15mH, 300-500mA | L1 | COMMON MODE CHOKE8.8X8.8EE8.3 | 1
4 | 14D471K | MOV1 | RES-TH_L16.5-W5.4-P7.50-D0.8-S2.80 | 1 | MOV-14D471K | BOURNS | LCSC | C1527439 | 0.455
5 | SMBJ5.0A | D1 | SMB_L4.6-W3.5-LS5.3-RD | 1 | SMBJ5.0A | ZHIDE(志得) | LCSC | C5161364 | 0.074
6 | HLK-PM01 | U5 | PWRM-TH_HLK-PM01 | 1 | HLK-PM01 | HI-LINK(海凌科) | LCSC | C209903 | 3.089
7 | BLM21SP111SH1D | U6 | BEAD-SMD_L2.0-W1.2-BLM21SP111SH1D | 1 | BLM21SP111SH1D | muRata(村田) | LCSC | C7220285 | 0.211
8 | 4.7k | R1,R2 | R1206 | 2 | RMC12064.7K5%N | Tyohm(幸亚电阻) | LCSC | C269760 | 0.008
9 | 10k | R3 | R1206 | 1 | RMC120610K5%N | Tyohm(幸亚电阻) | LCSC | C269752 | 0.008
10 | TBD62083 | U4 | SOP-18_L13.0-W7.0-P1.27-LS10.3-BL | 1 | TBD62083AFG,EL | TOSHIBA(东芝) | LCSC | C163228 | 0.878
11 | TCA9555PWR | U3 | TSSOP-24_L7.8-W4.4-P0.65-LS6.4-BL | 1 | TCA9555PWR | TI(德州仪器) | LCSC | C465732 | 0.842
12 | 100nF | C3,C5,C1 | C1206 | 3 | CSA1206X7R104K101MT | HRE(芯声) | LCSC | C48642912 | 0.033
13 | 100nF | C6 | C1206 | 1 | F | HRE(芯声) | LCSC | C48642912 | 0.033
14 | 10uF | C2 | C1206 | 1 | TCC1206X7R106K250HT | CCTC(三环) | LCSC | C380364 | 0.263
15 | 22uF | C4 | C1206 | 1 | TCC1206X7R226M100HT | CCTC(三环) | LCSC | C7393991 | 0.121
16 | 3.5INCH_DISPLAY_MODULE | LCD1 | 3.5INCH_TFT_DISPLAY_ILI9488 | 1 |  |  | Aliexpress
17 | SHT45 | U2 | DFN-4_L1.5-W1.5-P0.8-TL-EP | 1 | SHT45-AD1F-R2 | Sensirion(瑞士盛思锐) | LCSC | C5360602
18 | 250-208 | CN1 | CONN-TH_250-208 | 1 | 250-208 | WAGO(万可) | LCSC | C2833587
19 | G6RN-1A DC5 | K1,K2,K3,K4,K5 | RELAY-TH_G6RN | 5 | G6RN-1A DC5 | OMRON(欧姆龙) | LCSC | C1524532 | 6.727
20 | XIAO ESP32C5 | U1 | CONN-SMD_XIAO_ESP32C3 | 1 | XIAO ESP32C3 | null | LCSC | C19189385

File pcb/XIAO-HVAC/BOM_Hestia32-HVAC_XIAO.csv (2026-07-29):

ID | Name | Designator | Footprint | Quantity | Manufacturer Part | Manufacturer | Supplier | Supplier Part | Price
1 | 100nF | C1,C3,C5,C6,C8,C10 | C1206 | 6 | CSA1206X7R104K101MT | HRE(芯声) | LCSC | C48642912 | 0.033
2 | 10uF | C2 | C1206 | 1 | TCC1206X7R106K250HT | CCTC(三环) | LCSC | C380364 | 0.257
3 | 22uF | C4 | C1206 | 1 | TCC1206X7R226M100HT | CCTC(三环) | LCSC | C7393991 | 0.053
4 | 680uF | C7 | CAP-SMD_BD16.0-L17.0-W17.0-LS18.0-FD | 1 | EEVFK1H681M | PANASONIC(松下) | LCSC | C401970 | 1.851
5 | 470uF | C9 | CAP-TH_BD8.0-P3.50-D0.5-FD_470UF25VF140KM | 1 | 470UF25VF140KM | Econd(米朗电子) | LCSC | C46867098 | 0.026
6 | 250-208 | CN1 | CONN-TH_250-208 | 1 | 250-208 | WAGO(万可) | LCSC | C2833587
7 | DF06S | D1 | DFS_4P-L8.3-W6.4-P5.10-LS10.1-BL | 1 | DF06S-E3/77 | VISHAY(威世) | LCSC | C89064 | 0.476
8 | SS34 | D2 | SMB_L4.3-W3.6-LS5.4-RD | 1 | SS34 | DOWO(东沃) | LCSC | C2959729 | 0.038
9 | G6RN-1A DC5 | K1,K2,K3,K4,K5 | RELAY-TH_G6RN | 5 | G6RN-1A DC5 | OMRON(欧姆龙) | LCSC | C1524532 | 6.727
10 | 12uH | L1 | IND-SMD_L6.0-W6.0 | 1 | PNLS6045-120M 12UH | DMBJ(振宝佳) | LCSC | C2997653 | 0.077
11 | 3.5INCH_DISPLAY_MODULE | LCD1 | 3.5INCH_TFT_DISPLAY_ILI9488 | 1 |  |  | Aliexpress
12 | 4.7k | R1,R2 | R1206 | 2 | RMC12064.7K5%N | Tyohm(幸亚电阻) | LCSC | C269760 | 0.008
13 | 10k | R3 | R1206 | 1 | RMC120610K5%N | Tyohm(幸亚电阻) | LCSC | C269752 | 0.008
14 | XIAO ESP32C5 | U1 | CONN-SMD_XIAO_ESP32C3 | 1 | XIAO ESP32C3 | null | LCSC | C19189385
15 | SHT45 | U2 | DFN-4_L1.5-W1.5-P0.8-TL-EP | 1 | SHT45-AD1F-R2 | Sensirion(瑞士盛思锐) | LCSC | C5360602
16 | TCA9555PWR | U3 | TSSOP-24_L7.8-W4.4-P0.65-LS6.4-BL | 1 | TCA9555PWR | TI(德州仪器) | LCSC | C465732 | 0.787
17 | TBD62083 | U4 | SOP-18_L13.0-W7.0-P1.27-LS10.3-BL | 1 | TBD62083AFG,EL | TOSHIBA(东芝) | LCSC | C163228 | 0.875
18 | LM2596HVS | U5 | TO-263-5_L10.0-W9.0-P1.70-LS15.0-BL | 1 | LM2596HVS-5.0 | TECH PUBLIC(台舟) | LCSC | C18197847 | 1.011

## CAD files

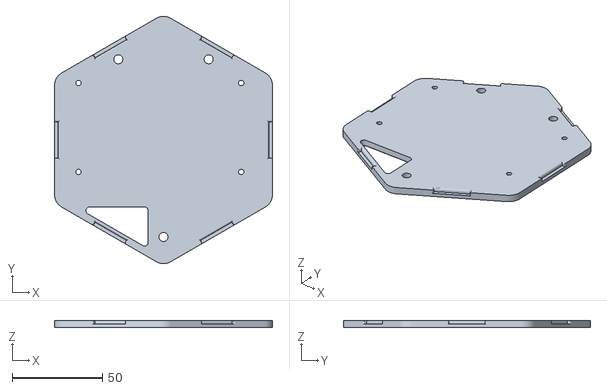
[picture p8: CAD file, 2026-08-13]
enclosure/Base32Snap.stl
120.6 x 136.8 x 4.00

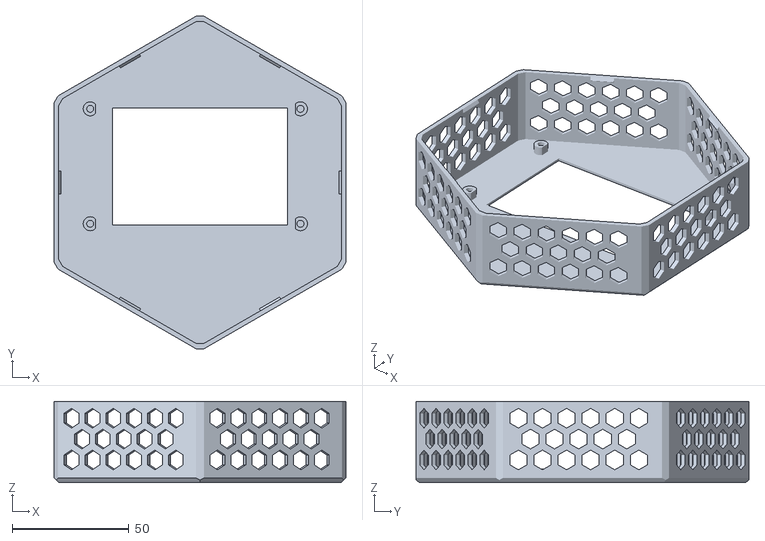
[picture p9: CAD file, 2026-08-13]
enclosure/Cover32Snap.stl
125.0 x 142.3 x 34.8

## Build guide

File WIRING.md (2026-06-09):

# Hestia32 ESP32-C5 Display Wiring Guide

This file was originally written for ESP32-C5-DevKitC-1 wiring. XIAO uses a different pin map and now has its own section below.

## ESP32-C5-DevKitC-1 Pinout (30-pin)

```
										ESP32-C5-DevKitC-1 (30-pin)

				 LEFT SIDE (15 pins)         RIGHT SIDE (15 pins)
		┌─────────────┐              ┌─────────────┐
		│ 3V3         │              │         GND │
		│ RTS         │              │         TX0 │ (GPIO 11)
		│ 2           │ Touch MISO   │         RX0 │ (GPIO 12)
		│ 3           │ Relay 3      │         24  │ Relay 5
		│ 0           │ Relay 1      │         23  │
		│ 1           │ Relay 2      │         15  │ Touch IRQ/PEN
		│ 6           │ SPI CLK      │         27  │
		│ 7           │ SPI MOSI     │         4   │ SHT45 SCL
		│ 8           │ Display DC   │         5   │ SHT45 SDA
		│ 9           │ Display RST  │         NC  │
		│ 10          │ Display CS   │         28  │
		│ 26          │ Relay 4      │         GND │
		│ 25          │              │         14  │ Touch CS
		│ 5V          │              │         13  │ Backlight
		│ GND         │              │         GND │
		└─────────────┘              └─────────────┘
		                   USB-C
```

### Pin Usage Summary
- **Power Rails**: 3.3V (left top), 5V (left bottom), GND (multiple)
- **Display**: GPIO 6-10, 13 (SPI + backlight)
- **Touch**: GPIO 2, 14, 15 (shared SPI on 6-7)
- **SHT45 Sensor**: GPIO 4 (SCL), GPIO 5 (SDA) - I2C
- **Relays**: GPIO 0, 1, 3, 26, 24
- **Reserved**: TX0/RX0 (GPIO 11/12 - UART0), GPIO 28 (BOOT), RTS

---

## XIAO ESP32-C5 Wiring (Current Firmware)

### XIAO ESP32-C5 Pinout (14-pin)

```
							 XIAO ESP32-C5 (top view)

								 USB-C CONNECTOR (top)
				LEFT SIDE (7 pins)         RIGHT SIDE (7 pins)
	 ┌─────────────┐               ┌─────────────┐
	 │ D0 / GPIO1  │ Display DC    │ 5V          │ VBUS
	 │ D1 / GPIO0  │ Backlight     │ GND         │ GND
	 │ D2 / GPIO25 │ Display RST   │ 3V3         │ 3V3
	 │ D3 / GPIO7  │ Display CS    │ D10 / GPIO10│ Display MOSI + Touch MOSI
	 │ D4 / GPIO23 │ I2C SDA       │ D9  / GPIO9 │ Touch MISO
	 │ D5 / GPIO24 │ I2C SCL       │ D8  / GPIO8 │ Display SCK + Touch SCK
	 │ D6 / GPIO11 │ Touch IRQ/PEN │ D7  / GPIO12│ Touch CS
	 └─────────────┘               └─────────────┘
	              ANTENNA SIDE (bottom)
```

//TODO: Pinout for both boards need verification and cleanup for useability
### XIAO Pin Usage Summary
- **Display**: GPIO 8,10,7,1,25
- **Touch**: GPIO 12,11,8,9
- **I2C (TCA9555/SHT45)**: GPIO 23,24
- **Power**: 5V, GND

### Important
- XIAO does not share the DevKit pin numbering layout. Do not wire XIAO using the DevKit table above.
- In firmware, XIAO display mapping is defined in `src/core/display_config.h` under `#ifdef CONFIG_BOARD_TYPE_XIAO`.
- **XIAO Relays**: Controlled via TCA9555 I2C GPIO expander pins 0-4 through TBD62083 driver channels.

### XIAO Relay Configuration (via TCA9555)
```
TCA9555 Pin 0 → Relay 1 control input (active-LOW)
TCA9555 Pin 1 → Relay 2 control input (active-LOW)
TCA9555 Pin 2 → Relay 3 control input (active-LOW)
TCA9555 Pin 3 → Relay 4 control input (active-LOW)
TCA9555 Pin 4 → Relay 5 control input (active-LOW)
```
Wire each TCA9555 output pin to relay-driver input negative, with input positive to +5V (same as DevKit).

### XIAO Display/Touch Pin Mapping

| Signal | XIAO GPIO | Notes |
|---|---|---|
| Display SCK | GPIO 8 | Seeed D8 |
| Display MOSI | GPIO 10 | Seeed D10 |
| Display MISO (unused) | Not connected - Display is write-only |
| Display CS | GPIO 7 | Seeed D3 |
| Display DC | GPIO 1 | Seeed D0 |
| Display RST | GPIO 25 | Seeed D2 - Required for reliable startup on XIAO |
| Backlight | GPIO 0 | Seeed D1, PWM-controlled with gradual boot ramp |
| Touch SCK | GPIO 8 | Seeed D8 |
| Touch CS | GPIO 12 | Seeed D7 |
| Touch IRQ/PEN | GPIO 11 | Seeed D6 |
| Touch MOSI | GPIO 10 | Seeed D10 |
| Touch MISO | GPIO 9 | Seeed D9 |

---

## ILI9488 3.5" IPS Display Connection

### Display Module Specifications
- Controller: ILI9488
- Size: 3.5 inches
- Resolution: 320x480 pixels
- Interface: SPI
- Touch: XPT2046 (Resistive)
- Panel Type: IPS

### Pin Connections

| Display Pin | ESP32-C5 GPIO | Notes |
|---|---|---|
| **Power** |||
| VCC | 3.3V | Power supply |
| GND | GND | Ground |
| **Display SPI** |||
| CS | GPIO 10 | Chip Select |
| RESET/RST | GPIO 9 | Hardware reset (NOT GPIO 11 - conflicts with U0TXD) |
| DC/RS | GPIO 8 | Data/Command select (NOT GPIO 12 - conflicts with U0RXD) |
| SDI/MOSI | GPIO 7 | SPI Data Out |
| SCK | GPIO 6 | SPI Clock |
| SDO/MISO | Not Connected | Leave disconnected - conflicts with touch controller |
| LED/BL | GPIO 13 | Backlight (PWM capable) |
| **Touch Controller (XPT2046)** |||
| T_CS | GPIO 14 | Touch Chip Select |
| T_PEN | GPIO 15 | Touch Pen Detect (active low) |
| T_DIN | GPIO 7 | Shared with MOSI |
| T_CLK | GPIO 6 | Shared with SCK |
| T_DO | GPIO 2 | Dedicated to touch (display MISO must be disconnected) |

### SPI Bus Configuration
- **SPI Host**: SPI2_HOST
- **Write Speed**: 40 MHz
- **Read Speed**: 16 MHz
- **Touch Speed**: 1 MHz
- **Mode**: SPI Mode 0 (CPOL=0, CPHA=0)

### Notes
1. **GPIO 11/12 Reserved**: These are U0TXD and U0RXD (UART0) - do not use for display
2. **Backlight Control**: GPIO 13 supports PWM for brightness adjustment
3. **CRITICAL - MISO Conflict**: Display SDO/MISO **must be disconnected**. The display and touch controllers cannot share GPIO 2. The display doesn't need MISO for normal operation (write-only), so GPIO 2 is dedicated to touch T_DO only.
4. **Touch PEN Pin**: Active low signal, triggers when pen is pressed. Same as IRQ/PENIRQ on other modules.
5. **Touch Calibration**: Automatic calibration wizard runs on boot. Touch all 5 crosshairs (corners + center) to calibrate. Calibration data is computed from corner samples with axis swap/flip detection.
6. **Level Shifting**: Not needed - ILI9488 modules typically have 3.3V logic

### Power Consumption
- Typical: ~150-200mA @ 3.3V (with backlight)
- Backlight off: ~20-30mA

### Optional: Add a capacitor
- 100µF capacitor between VCC and GND near the display recommended
- Helps stabilize power supply during screen updates

---

## SHT45 Temperature & Humidity Sensor

### Sensor Specifications
- Measures: Temperature, Humidity, Pressure
- Interface: I2C
- I2C Address: 0x76 (default) or 0x77

### Pin Connections

| SHT45 Pin | ESP32-C5 GPIO | Notes |
|---|---|---|
| VCC | 3.3V | Power supply |
| GND | GND | Ground |
| SDA | GPIO 5 | I2C Data |
| SCL | GPIO 4 | I2C Clock |

### I2C Configuration
- **I2C Port**: I2C_NUM_0
- **Speed**: 100 kHz (standard mode)
- **Pull-ups**: Internal pull-ups enabled

### Notes
1. SHT45 uses I2C interface with 7-bit addressing (address 0x44)
2. Default I2C address is 0x76, alternative is 0x77 (check your module)
3. Built-in driver handles calibration data and compensation automatically

---

## Relays

### Relay Configuration
- DevKit: 5 direct GPIO outputs
- XIAO: 5 outputs via TCA9555 pins 0-4 driving TBD62083 channels

### Pin Connections

| Relay | ESP32-C5 GPIO | Function | Notes |
|---|---|---|---|
| Relay 1 | GPIO 0  | Output 1 | Active LOW - GPIO LOW = Relay ON |
| Relay 2 | GPIO 1  | Output 2 | Active LOW - GPIO LOW = Relay ON |
| Relay 3 | GPIO 3  | Output 3 | Active LOW - GPIO LOW = Relay ON |
| Relay 4 | GPIO 26 | Output 4 | Active LOW - GPIO LOW = Relay ON |
| Relay 5 | GPIO 24 | Output 5 | Active LOW - GPIO LOW = Relay ON |

### Relay Control
- **Logic Level**: Configurable in firmware (`CONFIG_RELAY_ACTIVE_LOW`)
- **Wiring**: Relay control + pin → +5V, control - pin → ESP32 GPIO
- **Control Type**: Direct GPIO output (DevKit) or TCA9555 I2C expander (XIAO)

### Why Use Active-LOW (Optional)
- **Fail-safe**: GPIOs default HIGH during boot can keep relays OFF
- **Safety**: System crash or reset can keep outputs disabled
- **Current sinking**: GPIOs often sink current better than sourcing

### Notes
1. Relay driver inputs should be 3.3V-compatible
2. Relay load side may carry high voltage/current - ensure proper isolation and creepage
3. GPIOs selected to avoid conflicts with display (6-10, 13-15) and UART (11-12)
4. GPIOs selected to avoid display, touch, UART0, and BOOT-button pins

### PCB Wiring Example (per relay channel)
```
+5V ──────────────────────► [+] Relay Driver Input
							[-] Relay Driver Input ──► ESP32 GPIO (0, 1, 3, 26, or 24)

GND ───────────────────────────────────────────► Ground
```

When configured as active-LOW:
- GPIO = LOW (0V): Relay ON
- GPIO = HIGH (3.3V): Relay OFF

When configured as active-HIGH:
- GPIO = HIGH (3.3V): Relay ON
- GPIO = LOW (0V): Relay OFF

---

## GPIO Summary

### Reserved/In Use
| GPIO | Function | Notes |
|---|---|---|
| 0 | Relay 1 | Relay control |
| 1 | Relay 2 | Relay control |
| 2 | Touch MISO | XPT2046 data out |
| 3 | Relay 3 | Relay control |
| 4 | SHT45 SDA | I2C data |
| 5 | SHT45 SCL | I2C clock |
| 6 | SPI Clock | Shared display/touch |
| 7 | SPI MOSI | Shared display/touch |
| 8 | Display DC | Data/Command |
| 9 | Display RST | Reset |
| 10 | Display CS | Chip Select |
| 11 | UART0 TX | Reserved (serial) |
| 12 | UART0 RX | Reserved (serial) |
| 13 | Backlight | PWM control |
| 14 | Touch CS | Touch chip select |
| 15 | Touch IRQ | Touch interrupt |
| 26 | Relay 4 | Relay control |
| 24 | Relay 5 | Relay control |

### Available GPIOs
Check ESP32-C5 pinout under /docs/esp32-c5/ for additional available GPIOs not listed above.

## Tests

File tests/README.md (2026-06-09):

# Tests Directory

This directory contains test and diagnostic utilities for hardware validation.

## Available Tests
These tests can be compiled into the main firmware and called from `app_main()`.

### Power Consumption Test
**Files:** `power_test.c`, `power_test.h`
Needed by power profiler
- Tests all relay outputs
- Reads SHT45 sensor (I2C on GPIO 4 SCL, GPIO 5 SDA)
- Cycles through relay states

### RGB LED Test
**Files:** `rgb_led_test.c`, `rgb_led_test.h`
- Auto-detects LED type (addressable WS2812 vs separate RGB)
- Tests GPIO 27 for addressable LED
- Falls back to GPIOs 27, 25, 8 for separate R/G/B
- Cycles through colors to identify configuration

### Sensor Test
**Files:** `sensor_test.c`, `sensor_test.h`
- Reads SHT45 temperature and humidity
- Respects user temperature unit preference (°C / °F)
- Supports one-shot and periodic task modes

### Thermostat Logic Test
**Files:** `test_thermostat.c`
- Unit tests for thermostat control logic (no hardware required)

### I2C Scanner
**Files:** `i2c_scanner.c`, `i2c_scanner.h`
- Scans I2C bus addresses 0x03–0x77
- Labels known devices (SHT45 at 0x44, TCA9555 at 0x20)
- Probes SHT45 serial number and temperature/humidity measurement with CRC validation
- Probes TCA9555 input port register
- API: `void i2c_scanner_scan(int scl_pin, int sda_pin)`

## Standalone Test Projects

These are self-contained ESP-IDF projects that can be built and flashed independently without touching the main firmware.

### test_blink
**Path:** `test_blink/`
- Blinks the onboard LED on GPIO 27 at 2-second intervals
- Use to verify bare-minimum flash/boot on a fresh board

### test_i2c_scanner
**Path:** `test_i2c_scanner/`
- Standalone app that runs the I2C scanner in a loop every 3 seconds
- Configured for XIAO ESP32-C5 (SCL=GPIO24, SDA=GPIO23)
- Build and flash:
  ```bash
  cd tests/test_i2c_scanner
  source ~/esp/esp-idf-v5.5/export.sh
  idf.py set-target esp32c5
  idf.py build flash monitor
  ```

## Enabling Library Tests in Main Firmware

1. **Uncomment the test in `src/CMakeLists.txt`:**
   ```cmake
   set(test_sources
       # ${CMAKE_SOURCE_DIR}/tests/power_test.c
       # ${CMAKE_SOURCE_DIR}/tests/sensor_test.c
   )
   ```

2. **Include the test header in `src/main.c`:**
   ```c
   #include "../tests/power_test.h"
   #include "../tests/sensor_test.h"
   ```

3. **Call the test functions in `app_main()`:**
   ```c
   power_test_init();
   power_test_run();  // runs forever

   sensor_test_init();
   sensor_test_start_periodic_task(5000);  // every 5 seconds
   ```

4. **Important:** Most tests run in infinite loops or background tasks — place them at the end of `app_main()` after all other initialization.

## Notes
- Library tests are designed to be enabled one at a time
- Standalone test projects have their own `CMakeLists.txt` and `sdkconfig.defaults`
- Check serial monitor output for results
- Build outputs and generated `sdkconfig` files are excluded from version control via `.gitignore`

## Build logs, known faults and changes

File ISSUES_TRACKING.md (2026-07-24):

# Hestia32 Settings Enhancement - Issue Tracking

## Status Legend
- ✅ **DONE** - Implemented and verified
- 🔄 **IN PROGRESS** - Currently being worked on
- ⏸️ **PENDING** - Not yet started
- 🐛 **BUG** - Critical bug requiring immediate fix

---

## Critical Bugs

### 🐛 #12: Boot Flow Broken
**Name:** WiFi Provisioning Loop
**Status:** ✅ DONE
**Description:** Device unconditionally starts WiFi provisioning screen even when already provisioned. Factory reset also blocked during this state.
**Root Cause:** Boot flow logic missing WiFi provisioning check. Code structure corrupted during earlier edits.
**Fix:** Added `if (!wifi_prov_is_provisioned())` check before starting provisioning mode. Now only provisions when needed.
**Files Modified:** `src/main.c` (lines 305-330)

### ✅ #16: SHT45 Initialization and Error Handling
**Name:** SHT45/Relay Manager
**Status:** ✅ FIXED v4.1
**Description:** Series of cascading issues:
1. I2C driver install errors
2. Relay manager not initialized errors
3. "SHT45 not initialized" error flooding

**Root Causes:**
- **Phase 1 (I2C conflict):** Both TCA9555 and SHT45 tried to install I2C driver on same port → ESP_ERR_INVALID_STATE
- **Phase 2 (Missing init):** relay_manager_init() was never called in boot sequence
- **Phase 3 (Rollback damage):** Git rollback to fix compilation errors removed sensor_available flag, causing unconditional sht45_read() calls

**Fixes:**
- **v3:** SHT45 handles ESP_ERR_INVALID_STATE gracefully when I2C driver already installed
- **v4:** Added relay_manager_init() before SHT45 initialization
- **v4.1:** Re-added sensor_available flag to prevent reads when sensor init fails

**Files Modified:**
- `src/core/sensor_sht45.c` (lines 36-90: handle shared I2C driver)
- `src/main.c` (lines 253-261: relay manager init; lines 272-277: sensor_available flag; lines 299-301: conditional sensor read)

**Expected Logs:**
```
Initializing relay manager...
Relay manager initialized successfully
Initializing SHT45 sensor...
Using existing I2C driver (already initialized)
SHT45 sensor initialized successfully
```
**Name:** NTP Crash
**Status:** ✅ DONE
**Description:** Device crashes on boot with "assert failed: tcpip_callback" when WiFi is already provisioned. NTP initialization tries to use TCP/IP stack before it's ready.
**Root Cause:** `esp_sntp_setoperatingmode()` called at boot before WiFi/network stack initialized. This is a manifestation of issue #14.
**Fix:** Commented out NTP initialization calls (esp_sntp_setoperatingmode, esp_sntp_setservername, esp_sntp_init) until proper WiFi-aware init is implemented.
**Files Modified:** `src/main.c` (lines 365-369)
**Related:** Issue #14 will properly implement NTP init in WiFi connected event handler.

---

## UI/UX Enhancements - Locale Settings

### ✅ #1: Temperature Unit Label Visibility
**Name:** C Label Missing
**Status:** 🔧 FIXED (needs testing)
**Description:** "C" label touching the toggle switch while F has healthy margin.
**Fix:** Increased C label spacing from -106px to -120px (14px more margin from switch).
**Files Modified:** `src/core/ui/ui_settings_locale.cpp` (line 105)

### ✅ #2: Temperature Switch Color Behavior
**Name:** Switch Color
**Status:** ✅ VERIFIED FIXED (by user)
**Description:** In dark theme, switch becomes grey in C position, blue in F position.
**Root Cause:** LVGL switch widget uses grey color for unchecked indicator by default, making it hard to see in dark theme.
**Fix:** Added explicit background styling for LV_PART_MAIN (track background) using surface_variant color, and styled indicator for both checked and unchecked states.
**Files Modified:** `src/core/ui/ui_settings_locale.cpp` (lines 98-106)
**Name:** Switch Color
**Status:** 🔧 FIXED v3 (needs testing)
**Description:** In dark theme, switch becomes grey in C position, blue in F position.
**Previous Fix v2 Failed:** Only styled indicator part, but switch main background still had grey/blue default behavior.
**New Fix v3:** Explicitly style both indicator states and knob:
- Indicator (checked/F): Primary color
- Indicator (unchecked/C): Text secondary color (visible in dark theme)
- Knob: Dark grey (0x404040) - visible on both backgrounds
**Files Modified:** `src/core/ui/ui_settings_locale.cpp` (lines 95-98: added state-specific styling)
**Expected:** Both C and F positions clearly visible in dark theme

### ✅ #3: Real-Time Temperature Updates
**Name:** Temp Unit Callback
**Status:** 🔧 FIXED (needs testing)
**Description:** Units in current temp and Settings>Thermostat do not update when temperature unit is changed.
**Fix:** Added extensive debug logging throughout the refresh chain to diagnose the issue. Logs show unit conversion, cached data state, and all display updates.
**Files Modified:**
- `src/core/ui/ui_settings_locale.cpp` (lines 29-31: added debug logging)
- `src/core/ui/ui_main.cpp` (lines 1018-1067: added debug logging throughout refresh function)

### ✅ #4: Model-Based Temperature Defaults
**Name:** Model Temp Default
**Status:** 🔧 FIXED v3 (needs testing)
**Description:** Changing to HVAC shows Fahrenheit in settings UI, but main UI displays Celsius after reboot.
**Previous Fix v2 Failed:** 100ms delay wasn't enough or NVS read on boot had issues.
**New Fix v3:** Extended delay to 200ms, added read-back verification before reboot, and added boot-time logging to track temp unit value:
- Save temp unit to NVS
- Delay 200ms for NVS commit
- Read back and verify value matches
- Log verification result before reboot
- On next boot, log what temp unit was loaded from NVS
**Files Modified:**
- `src/core/ui/ui_settings_model.cpp` (lines 36-56: added verification and logging)
- `src/main.c` (lines 379-383: added boot-time temp unit logging)
**Expected Logs:**
```
Model changed to HVAC, setting temp unit to Fahrenheit (result: ESP_OK)
Verification: temp unit is now Fahrenheit (expected Fahrenheit)
Rebooting to apply model change...
[after reboot]
Temperature unit at boot: Fahrenheit
```
---

## UI/UX Enhancements - System Settings

### ⏸️ #5: Touch Pointer Visual Improvements
**Name:** Pointer Visuals
**Status:** ⏸️ PENDING
**Description:** Touch debug pointer currently disabled. Need themed appearance: 10px size, 70% opacity, themed color, 1px border.
**Implementation Plan:** Modify `display_manager.cpp` touch cursor creation (line 728), use theme primary/accent color, size 10px, LV_OPA_70, add border.
**Files To Modify:** `src/core/display_manager.cpp`

### ⏸️ #6: Touch Recalibration Button
**Name:** Recalibration Button
**Status:** ⏸️ PENDING
**Description:** Button exists in System settings but shows "coming soon" message. Need to wire to calibration wizard.
**Implementation Plan:** Call existing `run_touch_calibration()` function or create wrapper `display_manager_recalibrate()`.
**Files To Modify:**
- `src/core/ui/ui_settings_system.cpp` (on_recalibrate function)
- `src/core/display_manager.cpp` (expose calibration function)

### ⏸️ #7: OTA Install Implementation
**Name:** OTA Install
**Status:** ⏸️ PENDING
**Description:** OTA check works (queries GitHub API), but install button is stub.
**Implementation Plan:** Implement OTA download and flash sequence using `esp_https_ota` API.
**Files To Modify:** `src/core/ui/ui_settings_system.cpp`

---

## WiFi & Connectivity Enhancements

### ⏸️ #8: WiFi Standalone Provisioning
**Name:** WiFi Standalone
**Status:** ⏸️ PENDING
**Description:** WiFi provisioning currently coupled with calibration wizard. Should be accessible independently from Settings.
**Implementation Plan:** Add WiFi provisioning UI accessible from Connectivity settings, allow re-provisioning without factory reset.
**Files To Create/Modify:** New WiFi settings UI

### ⏸️ #9: WiFi Skip Button (First Boot)
**Name:** WiFi Skip
**Status:** ⏸️ PENDING
**Description:** On first boot, user should be able to skip WiFi provisioning to configure device locally first.
**Implementation Plan:** Add "Skip" button to provisioning UI that saves a flag and continues to main UI without WiFi.
**Files To Modify:** `src/core/ui/ui_provisioning.cpp`

---

## Time & NTP Enhancements

### ⏸️ #10: Show/Hide Time Toggle
**Name:** Time Visibility
**Status:** ⏸️ PENDING
**Description:** Time display should have show/hide toggle in Time settings.
**Implementation Plan:** Add toggle in time settings UI that controls visibility of time display in main UI. `device_config` already has `show_time` field.
**Files To Modify:**
- Time settings UI (add toggle)
- `src/core/ui/ui_main.cpp` (honor show_time flag)

### ⏸️ #11: Manual Time Entry
**Name:** Manual Time
**Status:** ⏸️ PENDING
**Description:** When NTP is disabled, user should be able to set time manually.
**Implementation Plan:** Create time picker UI (hour/minute spinners) that sets system time via `settimeofday()`.
**Files To Create/Modify:** New manual time entry UI

### ⏸️ #13: First-Boot NTP Prompt
**Name:** NTP Prompt
**Status:** ⏸️ PENDING
**Description:** On first boot, prompt user for NTP enable/disable, defaulting to "No".
**Implementation Plan:** Add NTP prompt screen during first boot sequence before main UI, save preference to NVS.
**Files To Create/Modify:** New first-boot NTP prompt UI

### ⏸️ #14: NTP WiFi-Aware Initialization
**Name:** NTP WiFi Check
**Status:** 🔄 IN PROGRESS (partially fixed with #15)
**Description:** NTP currently initializ3 fixes for #2, #4, #16)
**Binary Size:** 1,596,016 bytes (1.60 MB)
**Free Space:** 16% (303,504 bytes)
**Flash Command:** `idf.py -p /dev/ttyACM0 flash monitor`

**Recent Changes:**
- Switch visibility: Styled indicator states + knob color for dark theme
- HVAC temp unit: Added read-back verification and boot logging
- I2C driver: Handle ESP_ERR_INVALID_STATE when driver already installed by TCA9555
## Build Status

**Last Successful Build:** 2026-07-17 (v2 fixes for #2, #4, #16)
**Binary Size:** 1,596,336 bytes (1.60 MB)
**Free Space:** 16% (303,184 bytes)
**Flash Command:** `idf.py -p /dev/ttyACM0 flash monitor`

**Recent Changes:**
- Fixed switch visibility by removing main background override (use LVGL defaults)
- Fixed HVAC temp unit with 100ms delay + logging after NVS write
- Fixed SHT45 spam by using init result instead of sht45_is_available() probe

---

## Summary

**Total Issues:** 16
**Completed:** 2 (#12, #15)
**Fixed (needs testing):** 5 (#1, #2, #3, #4, #16)
**Pending:** 9
**Critical Bugs:** 3 (all fixed)

**Next Priority:** Test current fixes → #5 Touch Pointer Visuals → #6 Recalibration Button → #10 Time Visibility

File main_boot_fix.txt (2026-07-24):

// This is a backup file showing the new boot flow that should replace lines 168-280 in main.c

		// PRIORITY 1: Check if calibration exists - run wizard if needed BEFORE anything else
#if DISPLAY_ENABLED
		bool has_calibration = display_has_calibration();

		if (!has_calibration) {
				ESP_LOGI(TAG, "No calibration found - running wizard first");
				ret = display_init();
				if (ret == ESP_OK) {
						display_create_ui(false, false);  // Run calibration wizard
						ESP_LOGI(TAG, "Calibration complete - clearing display");
						display_clear_screen();
						display_update();
				}
				ESP_LOGI(TAG, "Restarting to continue boot sequence...");
				vTaskDelay(pdMS_TO_TICKS(1000));
				esp_restart();
		}

		/* Step 2: Initialize display with full UI */
		ESP_LOGI(TAG, "Initializing display...");
		ret = display_init();
		if (ret == ESP_OK) {
				display_create_ui(false, false);  // Load calibration from NVS, show full UI
				display_start_lvgl_task();  // Start dedicated LVGL task for UI updates
				ESP_LOGI(TAG, "Display initialized successfully");

				/* Step 3: Check if onboarding is needed (first boot or after factory reset) */
				if (ui_onboarding_needed()) {
						ESP_LOGI(TAG, "Onboarding needed, showing onboarding screen...");
						ui_onboarding_show();  // Blocks until user presses Continue
						ESP_LOGI(TAG, "Onboarding complete");
				}
		} else {
				ESP_LOGE(TAG, "Display initialization failed");
		}
#else
		ESP_LOGI(TAG, "Display disabled for this board configuration");
#endif

		// Initialize relay control
		ret = relay_manager_init();
		if (ret != ESP_OK) {
				ESP_LOGW(TAG, "Relay manager initialization failed (continuing anyway)");
		} else {
				ESP_LOGI(TAG, "Relay manager initialized");
		}

		/* Step 4: Check WiFi provisioning */
		ret = protocol_manager_init();
		if (ret != ESP_OK) {
				ESP_LOGE(TAG, "Protocol manager initialization failed");
				return;
		}

		bool is_provisioned = protocol_manager_is_provisioned();
		if (!is_provisioned) {
				ESP_LOGI(TAG, "Device not provisioned. Starting provisioning AP...");
				ESP_LOGI(TAG, "Connect to WiFi: %s", PROV_AP_SSID);
				ESP_LOGI(TAG, "Password: %s", PROV_AP_PASSWORD);
				ESP_LOGI(TAG, "Then open http://192.168.4.1 in your browser");

				ret = protocol_manager_start_provisioning();
				if (ret != ESP_OK) {
						ESP_LOGE(TAG, "Failed to start provisioning");
						return;
				}
				ESP_LOGI(TAG, "Provisioning started");

				// Wait for DHCP to initialize
				vTaskDelay(pdMS_TO_TICKS(2000));

#if DISPLAY_ENABLED
				/* Update display to show provisioning UI with skip option */
				ESP_LOGI(TAG, "Showing provisioning UI with skip option...");
				display_clear_screen();
				display_create_ui(true, true);  // Show provisioning UI

				/* Wait for either provisioning completion or skip button */
				while (1) {
						if (display_ui_provisioning_skip_pressed()) {
								ESP_LOGI(TAG, "User skipped WiFi provisioning - continuing without WiFi");
								break;
						}
						display_update();
						vTaskDelay(pdMS_TO_TICKS(100));
				}

				/* Reload main UI */
				display_clear_screen();
				display_create_ui(false, false);
#else
				ESP_LOGI(TAG, "Provisioning mode running headless (display disabled)");
				while (1) {
						vTaskDelay(pdMS_TO_TICKS(100));
				}
#endif
		}

		// Initialize sensors BEFORE starting WiFi to prevent blocking

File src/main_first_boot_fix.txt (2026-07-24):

			}
			if (!model_saved) {
					/* First-ever boot: write Kconfig default */
#ifdef CONFIG_HESTIA32_MODEL_EU
					device_config_t cfg;
					device_config_get(&cfg);
					cfg.model = DEVICE_MODEL_EU;
					cfg.domain_mask = (1<<0)|(1<<4);
					cfg.relay_map[0] = 0; cfg.relay_map[4] = 1;
					device_config_save(&cfg);
				/* EU model defaults to Celsius */
				user_settings_init();
				user_settings_set_temp_unit(TEMP_UNIT_CELSIUS);

				/* Set EU default setpoints: 22°C heat, 24°C cool */
				thermostat_settings_init();
				{
					thermostat_settings_t ts;
					thermostat_settings_get(&ts);
					ts.heat_setpoint_c = 22.0f;
					ts.cool_setpoint_c = 24.0f;
					thermostat_settings_save(&ts);
					ESP_LOGI(TAG, "EU model: setpoints set to 22°C / 24°C");
				}
#else
				device_config_t cfg;
				device_config_get(&cfg);
				cfg.model = DEVICE_MODEL_HVAC;
				cfg.domain_mask = (1<<0)|(1<<2)|(1<<4);
				cfg.relay_map[0] = 2; cfg.relay_map[2] = 0; cfg.relay_map[4] = 4;
				device_config_save(&cfg);
				/* HVAC model defaults to Fahrenheit */
				user_settings_init();
				user_settings_set_temp_unit(TEMP_UNIT_FAHRENHEIT);

				/* Set HVAC default setpoints: 72°F heat (22.2°C), 75°F cool (23.9°C) */
				thermostat_settings_init();
				{
					thermostat_settings_t ts;
					thermostat_settings_get(&ts);
					ts.heat_setpoint_c = 22.2f;  // 72°F
					ts.cool_setpoint_c = 23.9f;  // 75°F
					thermostat_settings_save(&ts);
					ESP_LOGI(TAG, "HVAC model: setpoints set to 72°F / 75°F (22.2°C / 23.9°C)");
				}
#endif
				ESP_LOGI(TAG, "First boot: device model initialized from Kconfig default");
		}
	}

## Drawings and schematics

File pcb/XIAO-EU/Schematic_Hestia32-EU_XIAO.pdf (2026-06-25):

# 3V3 12D10 11D9 10D8 9

## Main

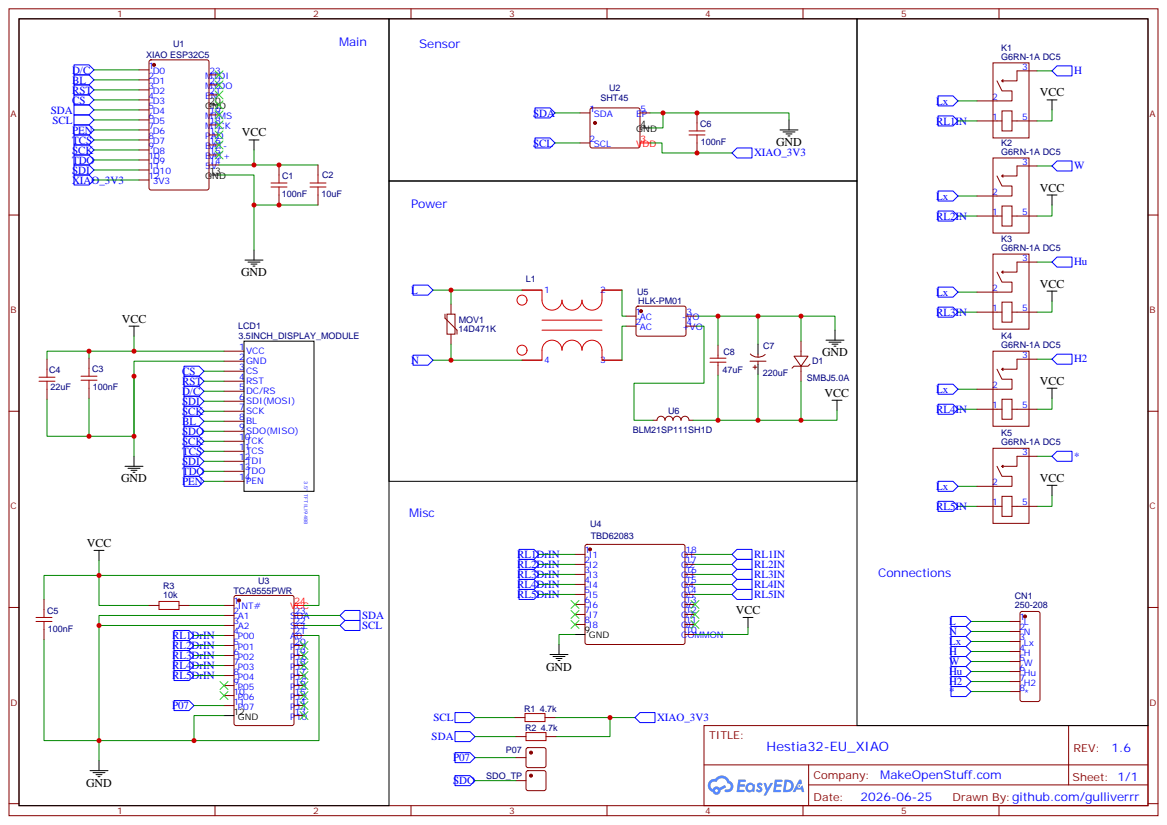
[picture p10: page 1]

Drawn By:github.com/gulliverrr

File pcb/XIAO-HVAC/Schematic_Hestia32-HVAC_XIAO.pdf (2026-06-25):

# 3V3 12D10 11D9 10D8 9

## Main

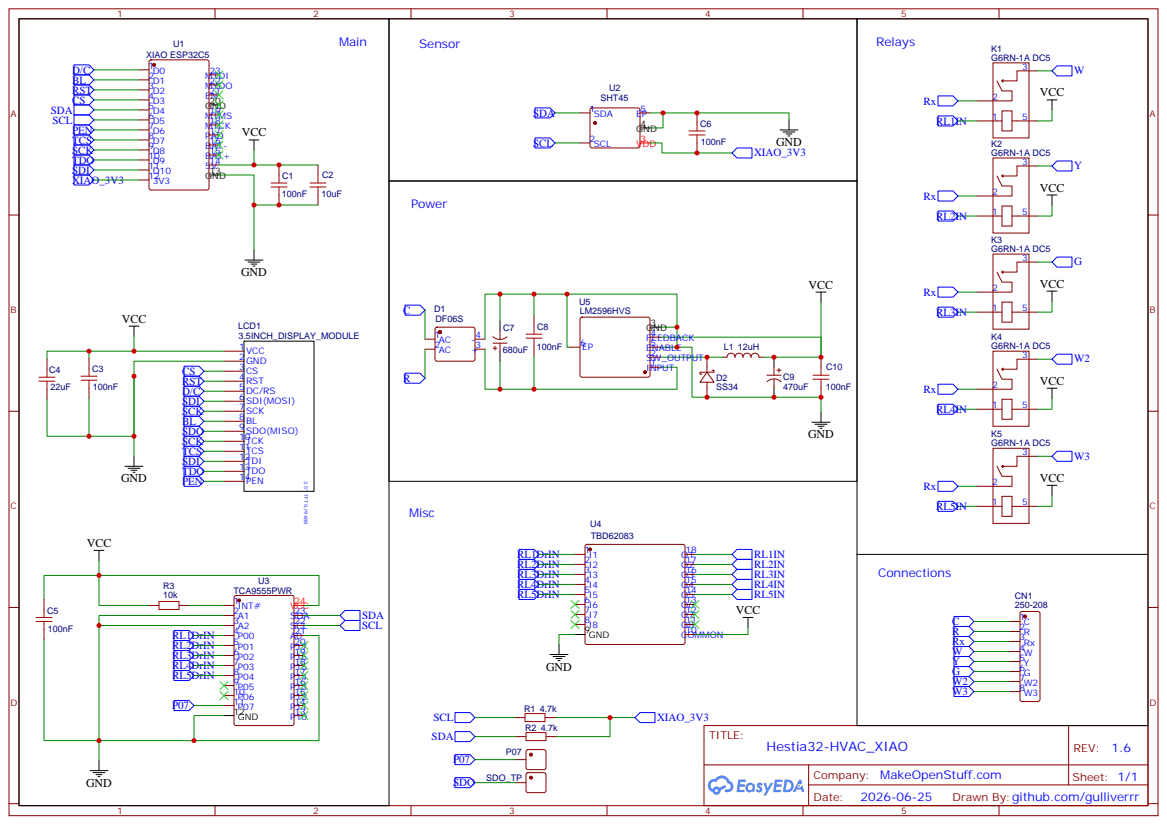
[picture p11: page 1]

Drawn By:github.com/gulliverrr

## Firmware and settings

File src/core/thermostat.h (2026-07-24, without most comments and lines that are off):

#define THERMOSTAT_H
#include <stdint.h>
#include <stdbool.h>
#ifdef __cplusplus
extern "C" {
#endif
#define THERMOSTAT_VERSION "1.0.0"
#define DEFAULT_HYSTERESIS_PERIOD_SEC       300   // 5 minutes between state changes
#define DEFAULT_HEAT_STAGE2_DELAY_SEC       600   // 10 minutes before engaging heat stage 2
#define DEFAULT_COOL_STAGE2_DELAY_SEC       300   // 5 minutes before engaging cool stage 2 (compressor less sensitive)
#define DEFAULT_MIN_CYCLE_TIME_SEC          180   // 3 minutes minimum run time
#define DEFAULT_FAN_PRE_RUN_SEC 30    // Fan starts 30s before thermal
#define DEFAULT_FAN_POST_RUN_SEC 60   // Fan continues 60s after thermal
#define DEFAULT_OPEN_WINDOW_TEMP_DROP_C     2.0f  // 2°C drop triggers detection
#define DEFAULT_OPEN_WINDOW_TIME_WINDOW_SEC 180   // Measure drop over 3 minutes
#define DEFAULT_OPEN_WINDOW_SUSPEND_SEC     900   // Suspend heating for 15 minutes
#define DEFAULT_OPEN_WINDOW_TEMP_DROP_C     2.0f  // 2°C drop triggers detection
#define DEFAULT_OPEN_WINDOW_TIME_WINDOW_SEC 180   // Measure drop over 3 minutes
#define DEFAULT_OPEN_WINDOW_SUSPEND_SEC     900   // Suspend heating for 15 minutes
#define DEFAULT_COMFORT_DEADBAND_C          0.5f
#define DEFAULT_ECO_DEADBAND_C              1.5f
#define TEMP_UNIT_DEFINED
typedef enum {
		TEMP_UNIT_CELSIUS,
		TEMP_UNIT_FAHRENHEIT
} TempUnit;
typedef TempUnit temp_unit_t;
typedef enum {
		COMFORT_MODE_COMFORT,
		COMFORT_MODE_ECO
} ComfortMode;
typedef enum {
		HUMIDITY_MODE_HUMIDIFY,
		HUMIDITY_MODE_DEHUMIDIFY
} HumidityMode;
typedef struct {
	uint32_t duration_sec;      // Last-set boost duration (seconds)
} BoostConfig;
typedef struct {
	temp_unit_t temp_unit;
	ComfortMode comfort_mode;
	HumidityMode humidity_mode;
	BoostConfig boost_heating;
	BoostConfig boost_cooling;
	BoostConfig boost_hot_water;
	bool heating_enabled;
	bool heating_stage2_enabled;     // Requires heating_enabled
	bool cooling_enabled;
	bool cooling_stage2_enabled;     // Requires cooling_enabled
	bool fan_enabled;
	bool humidity_control_enabled;
	bool hot_water_enabled;
	bool open_window_detection_enabled;
	float open_window_temp_drop_threshold;   // Temperature drop in degrees to trigger detection
	uint32_t open_window_time_window_sec;    // Time window to measure the drop (e.g., 3 minutes)
	uint32_t open_window_suspend_time_sec;   // How long to suspend heating after detection (e.g., 15 minutes)
		float heat_setpoint;
		float cool_setpoint;
		float humidity_setpoint;
		uint32_t hysteresis_period_sec;
		uint32_t heat_stage2_delay_sec;  // Delay before engaging heating stage 2
		uint32_t cool_stage2_delay_sec;  // Delay before engaging cooling stage 2
		uint32_t min_cycle_time_sec;
		uint32_t fan_pre_run_sec;   // Fan starts this many seconds before heating/cooling
		uint32_t fan_post_run_sec;  // Fan continues this many seconds after heating/cooling stops
	bool boost_active_heating;
	bool boost_active_cooling;
	bool boost_active_hot_water;
	uint32_t boost_end_time_heating;
	uint32_t boost_end_time_cooling;
	uint32_t boost_end_time_hot_water;
	uint32_t boost_last_duration_heating;
	uint32_t boost_last_duration_cooling;
	uint32_t boost_last_duration_hot_water;
		float comfort_deadband;
		float eco_deadband;
} ThermostatConfig;
typedef struct {
		float temperature;          // In configured unit
		float humidity;             // Relative humidity (0-100%)
		bool sensors_valid;         // False on sensor failure
		uint32_t now_seconds;
		bool fan_override;          // Force fan on
		bool hot_water_demand;      // Hot water requested
} ThermostatInput;
typedef enum {
		THERMAL_STATE_IDLE,
		THERMAL_STATE_HEATING,
		THERMAL_STATE_HEATING_STAGE2,
		THERMAL_STATE_COOLING,
		THERMAL_STATE_COOLING_STAGE2
} ThermalState;
typedef struct {
		ThermalState thermal_state;
		uint32_t thermal_state_enter_time;
		uint32_t last_state_change_time;
		bool fan_running;
		uint32_t fan_start_time;
		bool humidity_active;
		uint32_t humidity_start_time;
		bool hot_water_active;
		uint32_t hot_water_start_time;
		bool thermal_pending;           // Thermal wants to activate (waiting for fan pre-run)
		uint32_t thermal_pending_time;  // When thermal activation was requested
		uint32_t thermal_stop_time;     // When thermal stopped (for post-run)
	bool open_window_detected;      // Currently in open window mode
	uint32_t open_window_detect_time;   // When open window was detected
	float temperature_history[3];    // Last 3 temperature readings for trend detection
	uint32_t temperature_history_times[3];  // Timestamps for temperature readings
	uint8_t temperature_history_index;  // Current position in circular buffer
	bool boost_active_heating;
	bool boost_active_cooling;
	bool boost_active_hot_water;
	uint32_t boost_end_time_heating;
	uint32_t boost_end_time_cooling;
	uint32_t boost_end_time_hot_water;
	uint32_t boost_last_duration_heating;
	uint32_t boost_last_duration_cooling;
	uint32_t boost_last_duration_hot_water;
} ThermostatState;
typedef struct {
		bool heating_stage1;
		bool heating_stage2;
		bool cooling_stage1;
		bool cooling_stage2;
		bool fan;
		bool humidifier;        // If humidity_mode == HUMIDIFY
		bool dehumidifier;      // If humidity_mode == DEHUMIDIFY
		bool hot_water;
} ThermostatOutput;
void thermostat_update(const ThermostatConfig* config,
					  const ThermostatInput* input,
					  ThermostatState* state,
					  ThermostatOutput* output);
void thermostat_boost_activate(ThermostatState* state, const char* domain, uint32_t now, uint32_t duration_sec);
void thermostat_boost_cancel(ThermostatState* state, const char* domain);
bool thermostat_boost_is_active(const ThermostatState* state, const char* domain, uint32_t now);
void thermostat_config_init(ThermostatConfig* config);
bool thermostat_config_validate(const ThermostatConfig* config);
void thermostat_state_init(ThermostatState* state, uint32_t now_seconds);
void thermostat_update(
		const ThermostatConfig* config,
		const ThermostatInput* input,
		ThermostatState* state,
		ThermostatOutput* output
);
float thermostat_c_to_f(float celsius);
float thermostat_f_to_c(float fahrenheit);
#ifdef __cplusplus
}
#endif

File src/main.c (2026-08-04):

#include <stdio.h>
#include <string.h>
#include "freertos/FreeRTOS.h"
#include "freertos/task.h"
#include "esp_log.h"
#include "esp_system.h"
#include "esp_timer.h"
#include "nvs_flash.h"
#include "driver/gpio.h"

#include "core/core_config.h"
#include "core/display_config.h"
#ifdef CONFIG_PROTOCOL_MQTT
#include "protocols/mqtt/mqtt_config.h"
#include "protocols/mqtt/wifi_provisioning.h"
#endif
#include "core/protocol_manager.h"
#include "core/display_manager.h"
#include "core/display_ui.h"
#include "core/relay_manager.h"
#include "core/sensor_sht45.h"
#include "core/user_settings.h"
#include "core/core_config.h"
#include "ui/ui_onboarding.h"
#include "lvgl.h"

static const char *TAG = "main";

#if defined(CONFIG_BOARD_TYPE_DEVKIT) || defined(CONFIG_BOARD_TYPE_XIAO)
#define DISPLAY_ENABLED 1
#else
#define DISPLAY_ENABLED 0
#endif

static void log_active_pin_config(void)
{
#ifdef CONFIG_BOARD_TYPE_XIAO
		ESP_LOGI(TAG, "Board profile: XIAO ESP32-C5");
#else
		ESP_LOGI(TAG, "Board profile: ESP32-C5 DevKit");
#endif

		ESP_LOGI(TAG,
						 "Display pins: SCK=%d MOSI=%d CS=%d DC=%d RST=%d BL=%d TOUCH_CS=%d TOUCH_IRQ=%d TOUCH_MISO=%d",
						 TFT_SCLK, TFT_MOSI, TFT_CS, TFT_DC, TFT_RST, TFT_BL,
						 TOUCH_CS, TOUCH_IRQ, TOUCH_MISO);
		ESP_LOGI(TAG, "Display settings: enabled=%d pclk=%dHz", DISPLAY_ENABLED, LCD_PIXEL_CLOCK_HZ);
}

static void poll_factory_reset_button_runtime(void)
{
#if FACTORY_RESET_GPIO >= 0
		static bool s_button_init = false;
		static int s_hold_count = 0;

		if (!s_button_init) {
				gpio_config_t io_conf = {
						.pin_bit_mask = (1ULL << FACTORY_RESET_GPIO),
						.mode = GPIO_MODE_INPUT,
						.pull_up_en = GPIO_PULLUP_ENABLE,
						.pull_down_en = GPIO_PULLDOWN_DISABLE,
						.intr_type = GPIO_INTR_DISABLE,
				};
				gpio_config(&io_conf);
				s_button_init = true;
				ESP_LOGI(TAG, "Factory reset runtime button enabled on GPIO %d", FACTORY_RESET_GPIO);
		}

		if (gpio_get_level((gpio_num_t)FACTORY_RESET_GPIO) == 0) {
				s_hold_count++;
				if (s_hold_count == 1) {
						ESP_LOGW(TAG, "BOOT pressed: hold for 5 seconds to factory reset");
				}
				if (s_hold_count >= 5) {
						ESP_LOGW(TAG, "========================================");
						ESP_LOGW(TAG, "Factory reset confirmed (runtime button hold)");
						ESP_LOGW(TAG, "Erasing WiFi credentials and touchscreen calibration...");
						ESP_LOGW(TAG, "========================================");

						ESP_ERROR_CHECK(nvs_flash_erase());
						ESP_ERROR_CHECK(nvs_flash_init());

						ESP_LOGW(TAG, "Factory reset complete. Rebooting...");
						vTaskDelay(pdMS_TO_TICKS(1000));
						esp_restart();
				}
		} else if (s_hold_count > 0) {
				ESP_LOGI(TAG, "BOOT released before timeout (%d/5 seconds)", s_hold_count);
				s_hold_count = 0;
		}
#endif
}

// Relay test function - comment out the call in app_main() when not needed
static void test_relay_cycle(void)
{
		ESP_LOGI(TAG, "========================================");
		ESP_LOGI(TAG, "RELAY TEST: Cycling through all relays...");
		ESP_LOGI(TAG, "========================================");

		for (int cycle = 0; cycle < 1; cycle++) {
				ESP_LOGI(TAG, "Test cycle %d/3", cycle + 1);

				for (int relay = 0; relay < 4; relay++) {
						ESP_LOGI(TAG, "  Relay %d: ON", relay);
						relay_manager_set_relay(relay, true);
						vTaskDelay(pdMS_TO_TICKS(500));

						ESP_LOGI(TAG, "  Relay %d: OFF", relay);
						relay_manager_set_relay(relay, false);
						vTaskDelay(pdMS_TO_TICKS(300));
				}

				vTaskDelay(pdMS_TO_TICKS(500));
		}

		ESP_LOGI(TAG, "========================================");
		ESP_LOGI(TAG, "RELAY TEST: Complete!");
		ESP_LOGI(TAG, "========================================");
}

/**
 * Background task to start WiFi/protocol connection without blocking main task
 */
static void protocol_start_task(void* arg)
{
	ESP_LOGI(TAG, "Protocol start task running...");
	esp_err_t ret = protocol_manager_start();
	if (ret == ESP_OK) {
		ESP_LOGI(TAG, "Protocol started successfully");
	} else {
		ESP_LOGE(TAG, "Failed to start protocol");
	}
	vTaskDelete(NULL);  // Task exits after protocol starts
}

#if DISPLAY_ENABLED
// Task to handle display during provisioning
static void display_provisioning_task(void* param)
{
		esp_err_t ret = display_init();
		if (ret == ESP_OK) {
				display_create_ui(true, true);
				// Keep provisioning UI responsive while WiFi task continues independently.
				while (1) {
						display_update();
						vTaskDelay(pdMS_TO_TICKS(30));
				}
		}
		vTaskDelete(NULL);
}
#endif

void app_main(void) {
		ESP_LOGI(TAG, "========================================");
		ESP_LOGI(TAG, "Hestia32 ESP32-C5 Application");
		ESP_LOGI(TAG, "Firmware Version: %s", APP_VERSION);
		ESP_LOGI(TAG, "========================================");
		log_active_pin_config();

		// Initialize NVS
		esp_err_t ret = nvs_flash_init();
		if (ret == ESP_ERR_NVS_NO_FREE_PAGES || ret == ESP_ERR_NVS_NEW_VERSION_FOUND) {
				ESP_LOGW(TAG, "NVS partition was truncated, erasing...");
				ESP_ERROR_CHECK(nvs_flash_erase());
				ret = nvs_flash_init();
		}
		ESP_ERROR_CHECK(ret);
		ESP_LOGI(TAG, "NVS initialized");

		ESP_LOGI(TAG, "Factory reset: hold BOOT for 5 seconds while running");

// PRIORITY 1: Check if calibration exists - run wizard if needed BEFORE anything else
#if DISPLAY_ENABLED
bool has_calibration = display_has_calibration();

if (!has_calibration) {
ESP_LOGI(TAG, "No calibration found - running wizard first");
ret = display_init();
if (ret == ESP_OK) {
display_create_ui(false, false);  // Run calibration wizard
ESP_LOGI(TAG, "Calibration complete - clearing display");
display_clear_screen();
display_update();
}
ESP_LOGI(TAG, "Restarting to continue boot sequence...");
vTaskDelay(pdMS_TO_TICKS(1000));
esp_restart();
}
#else
ESP_LOGI(TAG, "Display disabled for this board configuration");
#endif

// Initialize relay control
ret = relay_manager_init();
if (ret != ESP_OK) {
ESP_LOGW(TAG, "Relay manager initialization failed (continuing anyway)");
} else {
ESP_LOGI(TAG, "Relay manager initialized");
}

/* Step 2: Check WiFi provisioning BEFORE initializing main UI */
ret = protocol_manager_init();
if (ret != ESP_OK) {
ESP_LOGE(TAG, "Protocol manager initialization failed");
return;
}

bool is_provisioned = protocol_manager_is_provisioned();

#if DISPLAY_ENABLED
/* Step 3: Initialize display */
ESP_LOGI(TAG, "Initializing display...");
ret = display_init();
if (ret != ESP_OK) {
ESP_LOGE(TAG, "Display initialization failed");
} else {
/* Check if onboarding is needed BEFORE creating main UI */
bool needs_onboarding = ui_onboarding_needed();

if (needs_onboarding) {
/* Start LVGL task (display_init already called, input device registered) */
display_start_lvgl_task();
ESP_LOGI(TAG, "Onboarding needed, showing onboarding screen...");
ui_onboarding_show();  // Blocks until user presses Continue
ESP_LOGI(TAG, "Onboarding complete");
display_clear_screen();  // Clear onboarding UI
}

/* Check WiFi provisioning status */
if (!is_provisioned) {
/* Show provisioning UI with skip option */
ESP_LOGI(TAG, "Device not provisioned. Starting provisioning AP...");
#ifdef CONFIG_PROTOCOL_MQTT
ESP_LOGI(TAG, "Connect to WiFi: %s", PROV_AP_SSID);
ESP_LOGI(TAG, "Password: %s", PROV_AP_PASSWORD);
ESP_LOGI(TAG, "Then open http://192.168.4.1 in your browser");
#endif

ret = protocol_manager_start_provisioning();
if (ret != ESP_OK) {
ESP_LOGE(TAG, "Failed to start provisioning");
ESP_LOGW(TAG, "Continuing without provisioning due to start error");
goto create_main_ui;
}
ESP_LOGI(TAG, "Provisioning started");

// Wait for DHCP to initialize
vTaskDelay(pdMS_TO_TICKS(2000));

/* Create provisioning UI */
display_create_ui(true, true);  // Show provisioning UI
if (!needs_onboarding) {
display_start_lvgl_task();  // Start LVGL if not already started
}

/* Wait for either provisioning completion or skip button */
while (1) {
if (display_ui_provisioning_skip_pressed()) {
ESP_LOGI(TAG, "User skipped WiFi provisioning - continuing without WiFi");
				/* Stop provisioning AP and mark as skipped */
#ifdef CONFIG_PROTOCOL_MQTT
				wifi_prov_mark_skipped();
				wifi_prov_stop_ap();
#endif
				break;
			}
			display_update();
			vTaskDelay(pdMS_TO_TICKS(100));
		}

		/* Clear provisioning UI before creating main UI */
display_clear_screen();
}

/* NOW create the main UI with timers (after onboarding and provisioning) */
create_main_ui:
display_create_ui(false, false);  // Load calibration from NVS, show full UI
if (!needs_onboarding && is_provisioned) {
    display_start_lvgl_task();  // Start LVGL if not already started (skipped both onboarding and provisioning)
}
ESP_LOGI(TAG, "Display initialized successfully");
}
#else
if (!is_provisioned) {
ESP_LOGI(TAG, "Device not provisioned. Starting provisioning AP...");
#ifdef CONFIG_PROTOCOL_MQTT
ESP_LOGI(TAG, "Connect to WiFi: %s", PROV_AP_SSID);
ESP_LOGI(TAG, "Password: %s", PROV_AP_PASSWORD);
ESP_LOGI(TAG, "Then open http://192.168.4.1 in your browser");
#endif

ret = protocol_manager_start_provisioning();
if (ret != ESP_OK) {
ESP_LOGE(TAG, "Failed to start provisioning");
return;
}
ESP_LOGI(TAG, "Provisioning started - running headless (display disabled)");
while (1) {
vTaskDelay(pdMS_TO_TICKS(100));
}
}
#endif

// Initialize sensors BEFORE starting WiFi to prevent blocking
	// Initialize relay manager and sensors BEFORE starting WiFi to prevent blocking		ESP_LOGI(TAG, "Initializing relay manager...");
		ret = relay_manager_init();
		if (ret == ESP_OK) {
			ESP_LOGI(TAG, "Relay manager initialized successfully");
		} else {
			ESP_LOGE(TAG, "Relay manager initialization failed: %s", esp_err_to_name(ret));
		}

		ESP_LOGI(TAG, "Initializing SHT45 sensor...");
		user_settings_init();

		/* Log current temperature unit setting */
		temp_unit_t boot_temp_unit = user_settings_get_temp_unit();
		ESP_LOGI(TAG, "Temperature unit at boot: %s",
		         boot_temp_unit == TEMP_UNIT_FAHRENHEIT ? "Fahrenheit" : "Celsius");
		// Use same I2C pins as TCA9555/relay manager
#ifdef CONFIG_BOARD_TYPE_XIAO
		ret = sht45_init(I2C_MASTER_SCL_IO, I2C_MASTER_SDA_IO);  // XIAO: GPIO 24 (SCL), GPIO 23 (SDA)
#else
		ret = sht45_init(4, 5);  // DevKit: GPIO 4 (SCL), GPIO 5 (SDA)
#endif

		bool sensor_available = (ret == ESP_OK);
		if (sensor_available) {
			ESP_LOGI(TAG, "SHT45 sensor initialized successfully");
		} else {
			ESP_LOGW(TAG, "SHT45 sensor initialization failed: %s (continuing anyway)", esp_err_to_name(ret));
		}
		ESP_LOGI(TAG, "Sensor availability status: %s", sensor_available ? "AVAILABLE" : "NOT AVAILABLE");

		// Start WiFi/protocol connection in background task to avoid blocking sensor readings
		ESP_LOGI(TAG, "Starting protocol connection in background...");
		xTaskCreate(
			protocol_start_task,
			"protocol_start",
			4096,
			NULL,
			5,
			NULL
		);

		ESP_LOGI(TAG, "Main initialization complete. Sensor loop starting.");

	// Wait for sensor to stabilize before first read (SHT45 needs ~1s warm-up)
	vTaskDelay(pdMS_TO_TICKS(1500));

	// Optional: Add application logic here or just suspend
	uint32_t last_sensor_read = 0;
	bool first_read_done = false;

	while (1) {
		// Main task suspended, other tasks (LVGL, WiFi, etc.) continue running
		poll_factory_reset_button_runtime();

		// Read sensor immediately on first iteration, then every 5 seconds
		uint32_t now = esp_timer_get_time() / 1000000;  // Convert to seconds
		if (!first_read_done || (now - last_sensor_read >= 5)) {
			if (sensor_available) {
				float temp, humidity;
				esp_err_t read_ret = sht45_read(&temp, &humidity);
				if (read_ret == ESP_OK) {
					float temp_converted = temp_to_user_unit(temp);
					const char* unit = user_settings_get_temp_unit_symbol();
					bool is_celsius = (user_settings_get_temp_unit() == TEMP_UNIT_CELSIUS);

					// Update display
					#if DISPLAY_ENABLED
					display_ui_update_sensor(temp_converted, humidity, is_celsius);
					#endif

					// Log to serial
					ESP_LOGI(TAG, "┌─────────────────────────────────┐");
					ESP_LOGI(TAG, "│ Temperature: %6.2f %-2s          │", temp_converted, unit);
					ESP_LOGI(TAG, "│ Humidity:   %6.1f %%            │", humidity);
					ESP_LOGI(TAG, "└─────────────────────────────────┘");

					first_read_done = true;
				} else {
					ESP_LOGW(TAG, "Sensor read failed: %s", esp_err_to_name(read_ret));
				}
			} else {
				if (!first_read_done) {
					ESP_LOGW(TAG, "Skipping sensor read - sensor not available");
					first_read_done = true;  // Don't spam this warning
				}
			}
			last_sensor_read = now;
		}

				vTaskDelay(pdMS_TO_TICKS(1000));
		}
}

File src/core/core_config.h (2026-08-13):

#ifndef CORE_CONFIG_H
#define CORE_CONFIG_H

#include "sdkconfig.h"

// Application Configuration
#ifndef APP_VERSION_SUFFIX
#define APP_VERSION_SUFFIX ""
#endif
#define APP_VERSION "0.9.0" APP_VERSION_SUFFIX

// Reset button configuration
// Set to -1 to disable, or a GPIO number to enable factory reset on boot
// To reset: hold this GPIO LOW for 5 seconds while firmware is running.
#ifdef CONFIG_BOARD_TYPE_XIAO
#define FACTORY_RESET_GPIO 28  // XIAO BOOT button (runtime long-press detection)
#elif CONFIG_IDF_TARGET_ESP32C5
#define FACTORY_RESET_GPIO 28  // Use GPIO 28 (BOOT button on ESP32-C5 DevKit)
#else
#define FACTORY_RESET_GPIO 0  // Use GPIO 0 (BOOT button on most ESP32 boards)
#endif

// I2C Configuration (for XIAO with TCA9555)
#ifdef CONFIG_BOARD_TYPE_XIAO
#define I2C_MASTER_NUM          I2C_NUM_0
#define I2C_MASTER_SDA_IO       23  // GPIO 23 (D4 on XIAO)
#define I2C_MASTER_SCL_IO       24  // GPIO 24 (D5 on XIAO)
#define TCA9555_I2C_ADDR        0x20
#endif

// Relay Configuration
#ifdef CONFIG_BOARD_TYPE_XIAO
// XIAO: Relays controlled via TCA9555 I2C GPIO expander
#define RELAY_USE_TCA9555       1
#define RELAY_TCA9555_PIN_BASE  0  // Relays on TCA9555 pins 0-4 (via TBD62083)
#else
// DevKit: Relays controlled via direct GPIO
#define RELAY_USE_TCA9555       0
#define RELAY_GPIO_1            0   // Relay 1
#define RELAY_GPIO_2            1   // Relay 2
#define RELAY_GPIO_3            3   // Relay 3
#define RELAY_GPIO_4            26  // Relay 4
#define RELAY_GPIO_5            24  // Relay 5
#endif

#define RELAY_COUNT             5

#ifdef CONFIG_RELAY_ACTIVE_LOW
#define RELAY_LEVEL_ON          0
#define RELAY_LEVEL_OFF         1
#else
#define RELAY_LEVEL_ON          1
#define RELAY_LEVEL_OFF         0
#endif

// OTA Internal RGB LED configuration
// WS2812 RGB LED for OTA status feedback (blue=downloading, green=success, red=error)
#define OTA_RGB_LED_GPIO 27

#endif // CORE_CONFIG_H

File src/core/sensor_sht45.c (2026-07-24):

#include "sensor_sht45.h"
#include "driver/i2c.h"
#include "esp_log.h"
#include "freertos/FreeRTOS.h"
#include "freertos/task.h"

static const char *TAG = "sht45";

#define I2C_MASTER_NUM I2C_NUM_0
#define I2C_MASTER_FREQ_HZ 100000  // 100kHz
#define I2C_MASTER_TIMEOUT_MS 1000

// SHT45 Commands
#define SHT45_CMD_MEASURE_HIGH_PRECISION 0xFD
#define SHT45_CMD_READ_SERIAL 0x89
#define SHT45_CMD_SOFT_RESET 0x94

static bool sht45_initialized = false;

/**
 * @brief Calculate CRC-8 for SHT45 data validation
 */
static uint8_t sht45_crc8(const uint8_t *data, int len) {
		const uint8_t POLYNOMIAL = 0x31;
		uint8_t crc = 0xFF;

		for (int j = len; j; --j) {
				crc ^= *data++;
				for (int i = 8; i; --i) {
						crc = (crc & 0x80) ? (crc << 1) ^ POLYNOMIAL : (crc << 1);
				}
		}
		return crc;
}

esp_err_t sht45_init(int scl_pin, int sda_pin) {
		if (sht45_initialized) {
				ESP_LOGW(TAG, "SHT45 already initialized");
				return ESP_OK;
		}

		i2c_config_t conf = {
				.mode = I2C_MODE_MASTER,
				.sda_io_num = sda_pin,
				.scl_io_num = scl_pin,
				.sda_pullup_en = GPIO_PULLUP_ENABLE,
				.scl_pullup_en = GPIO_PULLUP_ENABLE,
				.master.clk_speed = I2C_MASTER_FREQ_HZ,
		};

	/* Try to install I2C driver - if already installed by TCA9555, that's OK */
	esp_err_t ret = i2c_param_config(I2C_MASTER_NUM, &conf);
	if (ret != ESP_OK && ret != ESP_ERR_INVALID_STATE) {
		ESP_LOGE(TAG, "I2C param config failed: %s", esp_err_to_name(ret));
		return ret;
	}

	ret = i2c_driver_install(I2C_MASTER_NUM, conf.mode, 0, 0, 0);
	if (ret == ESP_OK) {
		ESP_LOGI(TAG, "I2C driver installed on SCL=%d, SDA=%d", scl_pin, sda_pin);
	} else if (ret == ESP_ERR_INVALID_STATE || ret == ESP_FAIL) {
		/* Driver already installed (probably by TCA9555/relay manager) - this is OK */
		/* Note: Some ESP-IDF versions return ESP_FAIL instead of ESP_ERR_INVALID_STATE */
		ESP_LOGI(TAG, "Using existing I2C driver (already initialized, code: %s)", esp_err_to_name(ret));
		ret = ESP_OK;  // Treat as success
	} else {
		ESP_LOGE(TAG, "I2C driver install failed: %s", esp_err_to_name(ret));
		return ret;
	}

	// Wait for I2C bus to stabilize
	vTaskDelay(pdMS_TO_TICKS(50));

	// Try to communicate with sensor
	if (!sht45_is_available()) {
		ESP_LOGE(TAG, "SHT45 sensor not detected at address 0x%02X", SHT45_I2C_ADDR);
		ESP_LOGE(TAG, "Check wiring: SCL should be on GPIO %d, SDA on GPIO %d", scl_pin, sda_pin);
		return ESP_ERR_NOT_FOUND;
	}

	// Wait for sensor to fully stabilize before first measurement
	vTaskDelay(pdMS_TO_TICKS(100));
	sht45_initialized = true;
	ESP_LOGI(TAG, "SHT45 sensor initialized successfully");
	return ESP_OK;
}

esp_err_t sht45_read(float *temperature, float *humidity) {
		if (!sht45_initialized) {
				ESP_LOGE(TAG, "SHT45 not initialized");
				return ESP_ERR_INVALID_STATE;
		}

		if (temperature == NULL || humidity == NULL) {
				ESP_LOGE(TAG, "NULL pointer passed to sht45_read");
				return ESP_ERR_INVALID_ARG;
		}

		uint8_t data[6];
		esp_err_t ret;

		// Send measurement command (high precision, no clock stretching)
		i2c_cmd_handle_t cmd = i2c_cmd_link_create();
		i2c_master_start(cmd);
		i2c_master_write_byte(cmd, (SHT45_I2C_ADDR << 1) | I2C_MASTER_WRITE, true);
		i2c_master_write_byte(cmd, SHT45_CMD_MEASURE_HIGH_PRECISION, true);
		i2c_master_stop(cmd);
		ret = i2c_master_cmd_begin(I2C_MASTER_NUM, cmd, pdMS_TO_TICKS(I2C_MASTER_TIMEOUT_MS));
		i2c_cmd_link_delete(cmd);

		if (ret != ESP_OK) {
				ESP_LOGE(TAG, "Failed to send measurement command: %s", esp_err_to_name(ret));
				return ret;
		}

		// Wait for measurement to complete (high precision: ~8.3ms, add margin for safety)
		vTaskDelay(pdMS_TO_TICKS(20));

		// Read 6 bytes: temp_msb, temp_lsb, temp_crc, hum_msb, hum_lsb, hum_crc
		cmd = i2c_cmd_link_create();
		i2c_master_start(cmd);
		i2c_master_write_byte(cmd, (SHT45_I2C_ADDR << 1) | I2C_MASTER_READ, true);
		i2c_master_read(cmd, data, 6, I2C_MASTER_LAST_NACK);
		i2c_master_stop(cmd);
		ret = i2c_master_cmd_begin(I2C_MASTER_NUM, cmd, pdMS_TO_TICKS(I2C_MASTER_TIMEOUT_MS));
		i2c_cmd_link_delete(cmd);

		if (ret != ESP_OK) {
				ESP_LOGE(TAG, "Failed to read measurement data: %s", esp_err_to_name(ret));
				return ret;
		}

		// Verify CRC for temperature
		if (sht45_crc8(data, 2) != data[2]) {
				ESP_LOGE(TAG, "Temperature CRC mismatch");
				return ESP_ERR_INVALID_CRC;
		}

		// Verify CRC for humidity
		if (sht45_crc8(data + 3, 2) != data[5]) {
				ESP_LOGE(TAG, "Humidity CRC mismatch");
				return ESP_ERR_INVALID_CRC;
		}

		// Convert raw values to physical units
		uint16_t temp_raw = (data[0] << 8) | data[1];
		uint16_t hum_raw = (data[3] << 8) | data[4];

		// SHT45 conversion formulas from datasheet
		*temperature = -45.0f + 175.0f * ((float)temp_raw / 65535.0f);
		*humidity = 100.0f * ((float)hum_raw / 65535.0f);

		// Clamp humidity to valid range
		if (*humidity < 0.0f) *humidity = 0.0f;
		if (*humidity > 100.0f) *humidity = 100.0f;

		ESP_LOGD(TAG, "Temperature: %.2f°C, Humidity: %.1f%%", *temperature, *humidity);
		return ESP_OK;
}

bool sht45_is_available(void) {
		i2c_cmd_handle_t cmd = i2c_cmd_link_create();
		i2c_master_start(cmd);
		i2c_master_write_byte(cmd, (SHT45_I2C_ADDR << 1) | I2C_MASTER_WRITE, true);
		i2c_master_stop(cmd);

		esp_err_t ret = i2c_master_cmd_begin(I2C_MASTER_NUM, cmd, pdMS_TO_TICKS(I2C_MASTER_TIMEOUT_MS));
		i2c_cmd_link_delete(cmd);

		return (ret == ESP_OK);
}

esp_err_t sht45_deinit(void) {
		if (!sht45_initialized) {
				return ESP_OK;
		}

		esp_err_t ret = i2c_driver_delete(I2C_MASTER_NUM);
		if (ret == ESP_OK) {
				sht45_initialized = false;
				ESP_LOGI(TAG, "SHT45 sensor deinitialized");
		}
		return ret;
}

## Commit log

2025-12-22 feat: WiFi provisioning with captive portal and factory reset
    [partitions_two_ota.csv]
2025-12-23 Add ESP32-C5 support with ESP-IDF v5.5
    - Add ESP32-C5 build configuration and sdkconfig.defaults
    - Add setup-c5.sh script for environment setup
    - Update CMakeLists.txt with component dependencies
    - Fix BOOT button GPIO: ESP32-C5 uses GPIO 28 (not GPIO 0)
    - Add comprehensive README with build instructions for both ESP32 and ESP32-C5
    - Update platformio.ini with note about ESP32-C5 requiring native ESP-IDF
    - Remove setup-c6.sh (not needed)
2025-12-24 Maximize OTA partition sizes to 1.81MB for 4MB flash
    - Updated partition table to use custom partitions_two_ota.csv
    - Changed flash size from 2MB to 4MB in sdkconfig
    - Increased NVS from 16KB to 24KB for better storage
    - OTA partitions now 1.81MB each (up from 1MB) - 81% increase
    - Removed factory partition (not needed with OTA)
    - Maximum app size now 1.81MB per OTA partition
    [partitions_two_ota.csv]
2026-01-02 Tune display performance: use 20MHz SPI pixel clock and increase LVGL buffer height to 80; adjust transaction queue depth
2026-01-02 feat: Add ILI9488 LCD panel and touch support
    - Implemented ILI9488 LCD panel driver in esp_lcd_ili9488.c and esp_lcd_ili9488.h.
    - Updated display_manager.h to include functions for checking touchscreen calibration and clearing the display.
    - Modified display_create_ui to accept parameters for skipping touchscreen calibration and WiFi provisioning mode.
    - Introduced a new task for handling display during WiFi provisioning in main.c.
    - Enhanced app_main to manage display initialization based on calibration status and provisioning state.
    [display_config.h, display_manager.cpp, esp_lcd_ili9488.c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]
2026-02-02 Add automatic OTA update system with GitHub integration
    Features:
    - NVS configuration storage for OTA settings (auto_update, channel, interval)
    - Semantic version comparison (handles v0.8.2, 0.8.2, pre-release suffixes)
    - GitHub API integration to check releases (stable/develop channels)
    - Partition space validation before download
    - HTTP resume support for interrupted downloads
    - Periodic check task with 5-minute initial delay
    - Exponential backoff on failures (1min → 2min → 4min → 8min)
    - Web provisioning UI with OTA settings
    - GitHub Actions workflow uploads individual .bin files for OTA
    Default: Auto-update ENABLED (for testing, TODO: disable once UI exists)
    Check interval: 24 hou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
2026-02-04 Release v0.8.4: OTA Memory Optimization & Auto-Update Control
    🎯 Major Features:
    - Full OTA update system with GitHub release checking
    - Memory-optimized display buffer management for OTA downloads
    - Visual feedback via RGB LED (blue=checking, green flash=success, red=error)
    - Automatic rollback protection with boot validation
    🔧 Technical Improvements:
    - Free display buffers (~110KB) during OTA to enable malloc(16384) for GitHub API
    - Smart buffer reallocation after OTA check completion
    - Suspend/resume LVGL task instead of full reinitialization
    - Display remains functional after "firmware up to date" check
    💡 OTA Visual Feedback:
    - Blue LED during GitHub API check and firmware down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
    [core_config.h, display_manager.cpp]
2026-02-10 Add I2C SHT45 sensor support
    - Implemented i2c_scanner.c and i2c_scanner.h for scanning I2C bus devices.
    - Created sensor_test.c and sensor_test.h to initialize and read from the SHT45 sensor.
2026-03-11 feat: Support Seeed XIAO ESP32-C5
    - Added relay_manager.c and relay_manager.h to manage relay states.
    - Implemented initialization, deinitialization, and state control for relays.
    - Integrated support for TCA9555 I2C GPIO expander.
    - Added functions to set and get individual relay states and all relays at once.
    - Updated main application to initialize relay manager and perform relay test cycles.
    fix: Improve error handling in WiFi manager and OTA manager
    - Enhanced error logging in wifi_manager.c for NVS and event loop initialization.
    - Added detailed error messages for WiFi disconnection reasons.
    - Updated OTA manager to restore display state on errors during GitHub release checks.
    test: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
    [core_config.h, display_config.h, display_manager.cpp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]
2026-04-02 Add support for XIAO relay control and update wiring documentation prior to PCB design
2026-04-09 Add Gerber and BOM files (in pcb folder)
    [BOM_Hestia32-EU_XIAO.csv, BOM_Hestia32-HVAC_XIAO.csv]
2026-04-22 PCB version 1.1
    - Fix I2C pull up resistors
    - Renumerate components prefixes without gaps
    - Add unpopulated additional GPIOs pins from port expander (P07)
    - Increase clearance around holes in case user uses large metal screw or washer
    - Add extra information on top silkscreen
    - Add schematic in PDF and SVG format
    [BOM_Hestia32-EU_XIAO.csv, BOM_Hestia32-HVAC_XIAO.csv]
2026-04-25 Add PCB assembly image to README
2026-04-25 PCB version 1.2
2026-04-25 chore: bump firmware to v0.9.0 and update release documentation
    - Update APP_VERSION to 0.9.0 in src/core/core_config.h
    - Update FSD firmware version metadata and revision history
    - Expand README Features section with HVAC, Boost, protocols, board variants
    - Update Project Structure to reflect src/core and src/protocols organization
2026-04-29 Add interactive BOM files for XIAO-EU and XIAO-HVAC, link in pcb/README [skip ci]
2026-05-19 Use coil relays, support heat pumps, improve filtering and power supply.
    [BOM_Hestia32-EU_XIAO.csv, BOM_Hestia32-HVAC_XIAO.csv]
2026-05-19 XIAO-HVAC v1.4: Use LM2596HVS instead of LM2596S
    [BOM_Hestia32-HVAC_XIAO.csv]
2026-05-20 XIAO-HVAC 1.5 + XIAO-EU 1.4: Added LCD SDO test point and changed 3V3 label
    [BOM_Hestia32-EU_XIAO.csv, BOM_Hestia32-HVAC_XIAO.csv]
2026-06-09 Enhance relay management: support five relays, add active-low configuration, and update documentation
2026-06-25 XIAO-HVAC 1.6 + XIAO-EU 1.6: Remove copper fill around sensor and add air gap
2026-07-08 Update README.md: Enhance relay control description
2026-07-24 fix: guard MQTT-specific WiFi provisioning calls
    Wrap wifi_prov_mark_skipped(), wifi_prov_stop_ap(), and PROV_AP_*
    macros with CONFIG_PROTOCOL_MQTT guards to fix Zigbee and Matter
    protocol builds.
    [main.c]
2026-07-29 BOM minor issue
    [BOM_Hestia32-EU_XIAO.csv, BOM_Hestia32-HVAC_XIAO.csv]
2026-08-03 fix: update C8 part number in BOM file for XIAO-EU
    [BOM_Hestia32-EU_XIAO.csv]
2026-08-03 fix: improve display wake and sleep handling to prevent image retention
    [display_manager.cpp]
2026-08-13 Add WiFi indicator and enhance connectivity settings UI
    [Base32Snap.stl, Cover32Snap.stl]
2026-10-11 feat: update enclosure for symmetric LCD placement, documentation and mark completed tasks on enclosure README
2026-10-13 Complete development for Generic DevKit boards
